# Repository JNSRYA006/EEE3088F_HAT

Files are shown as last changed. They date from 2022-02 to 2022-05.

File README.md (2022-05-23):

# Autonomous Plant Monitoring HAT for Discovery Board with STM32F051x8
This repository will be updated at each stage of the design process, and where necessary changes are made.

# Group Members:
* Ryan Jones (JNSRYA006)
* Alex Cargill (CRGALE002)
* Devlin Trafford (TRFDEV001)

# Project Details
### This project is part of a project for EEE3088F in 2022
This project will design a HAT *(Hardware Attached on Top)* for a STM Discovery Board which uses the STM32F051x8. The use case for this HAT is for semi-autonomous indoor plant growing. It will have a temperature sensor located as close to the plant as possible as well as a light sensor facing the main direction which the plant receives light from . These sensors will connect to a STM Discovery board, which will act as the brain of the system. This design was created for small scale agricultural setups. Appropriate user stories were applied to develop the Specifications. Given these use cases, the PCB is able to:

* Monitor the **temperature** around a plant
* Get precise readings of the **light level** a plant is receiving. 

See a 3D render of the PCB from KiCad below,

| PCB 3D Render |
| :----------------------------------------------------------: |

## Repository Structure
### Each sub-folder contains different aspects relating to different parts of the project
* ***PCB:*** The KiCad Project, Schematics, PCB & Layout and Project Libraries
* ***Firmware:*** Any software developed for the hardware or instructions on where to find relevant sofware in cases where it makes more sense to have this in its own dedicated repo
* ***Docs:***  Project documentation, Draft documents, ERC & DRC reports, project handins, schematic screenshot & documents and component datasheets
* ***Production:*** The final gerber files, BOM, Budget, or anything required by the fabrication houses
* ***Simulation:*** Any simulation files (SPICE) or design stage generated results (matlab or excel) 
* ***CAD:*** Any 3D models or mechanical designs for enclosures or support
# Hardware Requirements
 * [ ] STMDiscovery Board with an STM32F051x8 μC
 * [ ] 1 x MicroUSB to USB-A Cable
 * [ ] 1x MiniUSB to USB-A Cable
 * [ ] 8x Male to Female Jumpers

# Software Requirements

 - [ ] Computer 
	 - *Windows, Linux or MACOS*
 - [ ] STM32Cube IDE
	 - [Download available online](https://www.st.com/en/development-tools/stm32cubeide.html#get-software)
 - [ ] PuTTY
	 - [Download available online](https://www.chiark.greenend.org.uk/~sgtatham/putty/latest.html)

# How to short the UVLO circuit

- On the LHS of the board, remove resistor **R12 & R10** using pliers and twisting and pulling the resistors

- Q1 & IC1 (Circled in **Orange**) are the MOSFET & Op-Amp in the UVLO circuit that needs to be removed by soldering one end of a wire to the top pad (Pad 2) of R12 to the top pad (Pad 2) of R10 (Circled in **Green**)

  | UVLO_shorting |
  | :----------------------------------------------------------: |

# How to connect the power module to the rest of the board

- On the top, RHS of the board, solder a wire between **TP9** *OR* the **+3V** pin pad and the right hand pin of **J7**
  - This will connect the power from the power module to the rest of the circuit
- If connected correctly, when a battery is inserted or a USB is connected, a **Red** diode (**D9**) will turn on to indicate the sensing and microcontroller sub-circuits are receiving power.

# How to connect the PCB to the STMDiscovery Board

The following locations **on the PCB** need to be soldered to the male end of the jumper:

(*Refer to the KiCad PCB file [here](https://github.com/JNSRYA006/EEE3088F_HAT/blob/main/PCB/main/main.kicad_pcb) for the exact location of these*)

- PA1
- PA2
- PA9
- PA10
- PB6
- PB7

The female end of these jumpers are then connected to the corresponding pins on the STMDiscovery board.

# How to connect the PCB & STMDiscovery to your computer using UART

- Download and install CH340 drivers
  - [Download available online](https://learn.sparkfun.com/tutorials/how-to-install-ch340-drivers/all#drivers-if-you-need-them)
- Plug the device to your computer using a USB port. 
  - Check that the device is visible under ports in the Device Manager (for *Windows*), 
    - [Instructions on how to open Device Manager here](https://www.lifewire.com/how-to-open-device-manager-2626075)
- Create a serial connection with a baud rate of 18400bits/s in PuTTY

# How to send your first data to the board!

- After connecting the board using the above instructions,
- Type “Hello HAT” into the console and press ENTER.
- The device will dump all information collected since the last time the device was connected to a USB host device in the terminal window

# Contributing to this project

You're more than welcome to contribute to this project! Please take a look at our CONTRIBUTING.md file linked here

# License

[Creative Commons Attribution 4.0 International license](https://choosealicense.com/licenses/cc-by-4.0/)

[MIT License](https://choosealicense.com/licenses/mit/)

#

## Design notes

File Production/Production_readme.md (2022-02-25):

# Production
This folder will include instructions for the production of the PCB and will including budgeting notes.

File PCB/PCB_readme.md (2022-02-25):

# PCB notes
## From Justin's notes:
"In this repository a second repo has been added as a submodule and is available in the libraries folder [here](./PCB/Library/kicad6-libraries/).  This is an example of storing all the symbols and footprints you collect and make over time in a single location.  Go and look at the source of this submodule [here](https://gitlab.com/r4space/kicad6-libraries.git).  

The advantage of this approach is that as you develop more PCBs you will collect and create an increasing number of custom symbols and footprints that are not provided in the std KiCAD libraries.  By adding this submodule to all of your projects you will always have access to this extended library.  The cost of this, however, is clearly that your project repos will get increasingly large as your personal library grows.  In the context of collaborative work in a company, this would not be a problem and the company likely has exactly such a custom in-house set of libraries and the repos are not released to a client with the entire submodule but rather a specific release repo is made for this.

For the project, this is an effective way of starting your own libraries repo and collaborating.

At any point, you are able to enter the folder containing this submodule and updating it via a normal git pull."

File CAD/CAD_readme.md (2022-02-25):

# Project CAD Files
This folder will contain all files related to mechanical design for the project such as 3D printing or other container design files.

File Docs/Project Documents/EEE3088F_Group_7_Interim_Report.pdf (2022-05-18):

# EEE088F 2022 Interim Design Report Autonomous Plant Monitoring HAT for Discovery Board with STM32FC051

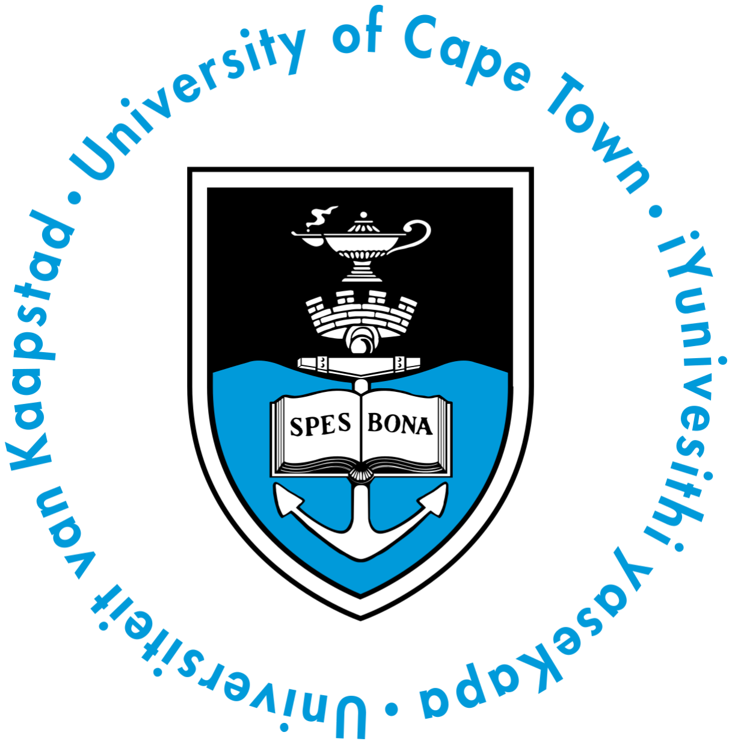
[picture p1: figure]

# JNSRYA006 TRFDEV001 CRGALE002

22/04/2022

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
cific

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
olle

r in

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
olle

r in

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
al [

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
# 1 Executive Summary [5]

The following report documents the design process and current design of a Discovery Board HAT (Hardware Attached on Top) for a STM32 Microcontroller. The use case for this HAT is for semi-autonomous indoor plant growing. All fianl PCB design files are available in a GitHub repository at this link. (https://github.com/JNSRYA006/EEE3088F_HAT)

This design was created for small scale agricultural setups. Appropriate user stories were applied to develop the Specifications. Given these use cases, the PCB is able to: Monitor the temperature around a plant, get precise readings of the light level a plant is receiving. These measurements can then be used to integrate with a control system that can adjust the temperature and light that a plant receives.

This device was thoroughly designed and the PCB has dimensions of: 96.01 mm x 70.01 mm, weighs ~0.11kg per board and costs $14.576 per board (excl. Shipping from JLCPCB). The device measures Temperature with an accuracy of (-10℃ to +85℃): ±1℃, at a 9-12 bit resolution. The device measures Light with an accuracy of < 3% Photocurrent Fluctuation versus Temperature Change (0℃ to 60 ℃) and the device operates at 5V via an input voltage from a USB or at 3.6V Input Voltage via 18650 Li-Ion Battery.

# 2 Introduction [15]

The use case for this project is autonomous and semi-autonomous indoor grow operations. This could be used in scenarios where someone would want to remotely monitor and control the environmental conditions of their growing operation or in scenarios where the operation is too large for the individual monitoring of environmental conditions and the system must self-monitor.

This sensing unit is designed to monitor two crucial factors in the growth of all crop-yielding plants: Heat and Ambient Light.
Most crop yielding plants grow in the temperature range of 15-30℃ (the large majority being around 21℃). Thus both sensors will need to operate effectively in this temperature range. It is also important that the ambient light sensor be sensitive to the spectrum of light required to grow plants.The wavelength of light that plants predominantly use for photosynthesis ranges from 600–800 nm. Thus the light sensor should be sensitive to this range of light frequencies.

These sensor readings would then be used to control the cooling/heating system and lighting system of the grow environment. This would allow for correction in the case of heat or light being sub-optimal.

Temperature Sensor Resolution: 9-12 bit resolution
Temperature Sensor Accuracy (-10℃ to +85℃): ±1℃
Light Sensor Accuracy: < 3% Photocurrent Fluctuation versus Temperature Change (0℃ to 60 ℃)
Operating voltage: 5V Input Voltage via USB OR 3.6V Input Voltage via 18650 Li-Ion Battery
Typical Power Consumption: 32324.16 mW = 32.32416 W
Cost:
- $14.576 per board
- Shipping from JLCPCB ≈ $26.53 for 5 Boards
- ~ $99.41 for 5 Boards (incl. shipping) Interfaces: USB, UART, I

2C, 1-wire protocol

## 2.1 Project Subsystems Block Diagram [10]

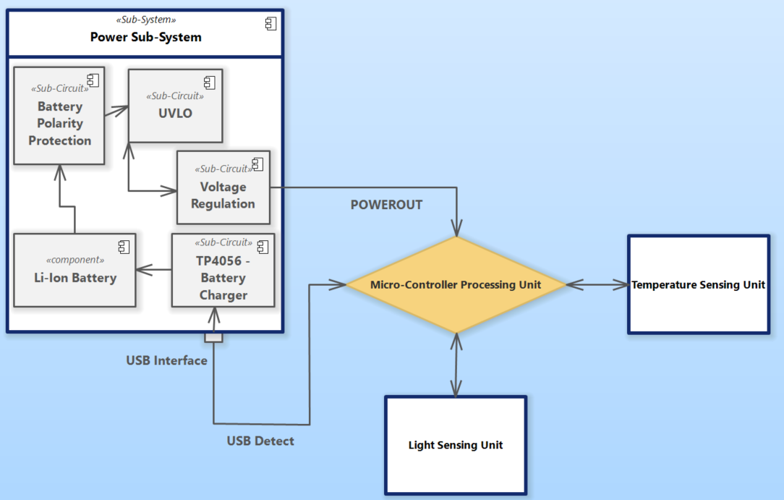
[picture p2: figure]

Figure 1: Project Sub-System Block Diagram

# 3 Specifications [15]

## 3.1 Power subsystem submodule [5]

### Sub-Module Top Level Specifications:

- Inputs:
- V | = 5V via USB Input at a maximum current of 4A CCIN ■ The typical current drawn will be ~2.5A
- V | = ~3.6V via an 18650 battery at a maximum current of 3A
BAT
| ■ The typical current drawn will be ~2.5A
- Outputs:
- V = 3.3V
OUT
- D+ & D- from USB to Microcontroller Sub-Module
- Visual User Communication Interfaces:
- The charging circuit has two LEDs (D5 & D6) located below the battery holder in the locations shown below in Figure 2.

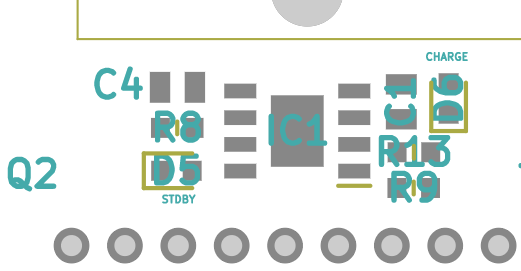
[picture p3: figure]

Figure 2: Location of CHARGE & STDBY LEDs on the PCB

Charge State | Red LED (CHARGE) | Green LED (STBY)
Charging | ON | OFF
Battery Fully Charged | OFF | ON
Vin too low | OFF | OFF
No battery connected | OFF | OFF
Figure 3: LED Charging State Table
- Furthermore, there is a Red LED located next to the USB input IC (MICROXNJ) that shows whether or not a USB has been detected using the following state table.

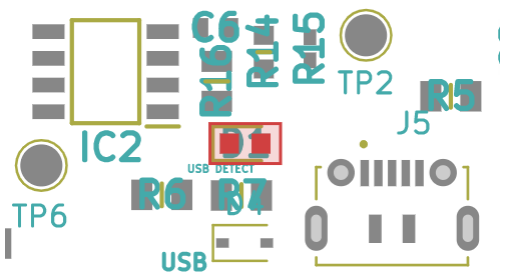
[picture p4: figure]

Figure 4: Location of USBDETECT LED on the PCB

USB Connection State | Red LED (USBDETECT)
NO USB Connected | OFF
USB Connected | ON
Figure 5: USB Connection State Table
- Interfaces with other modules:
- 3.3V will be delivered by the Power Module to the 3V3 Pin (Pin 1) on the 32 pin connector (J2). The other modules will access this power from the pin.
- Within the sub-module, the ICs will connect to each other in as short a routing as possible. With this, before each power pin of each IC, a decoupling capacitor has been added to remove any noise in the power provided to the ICs.

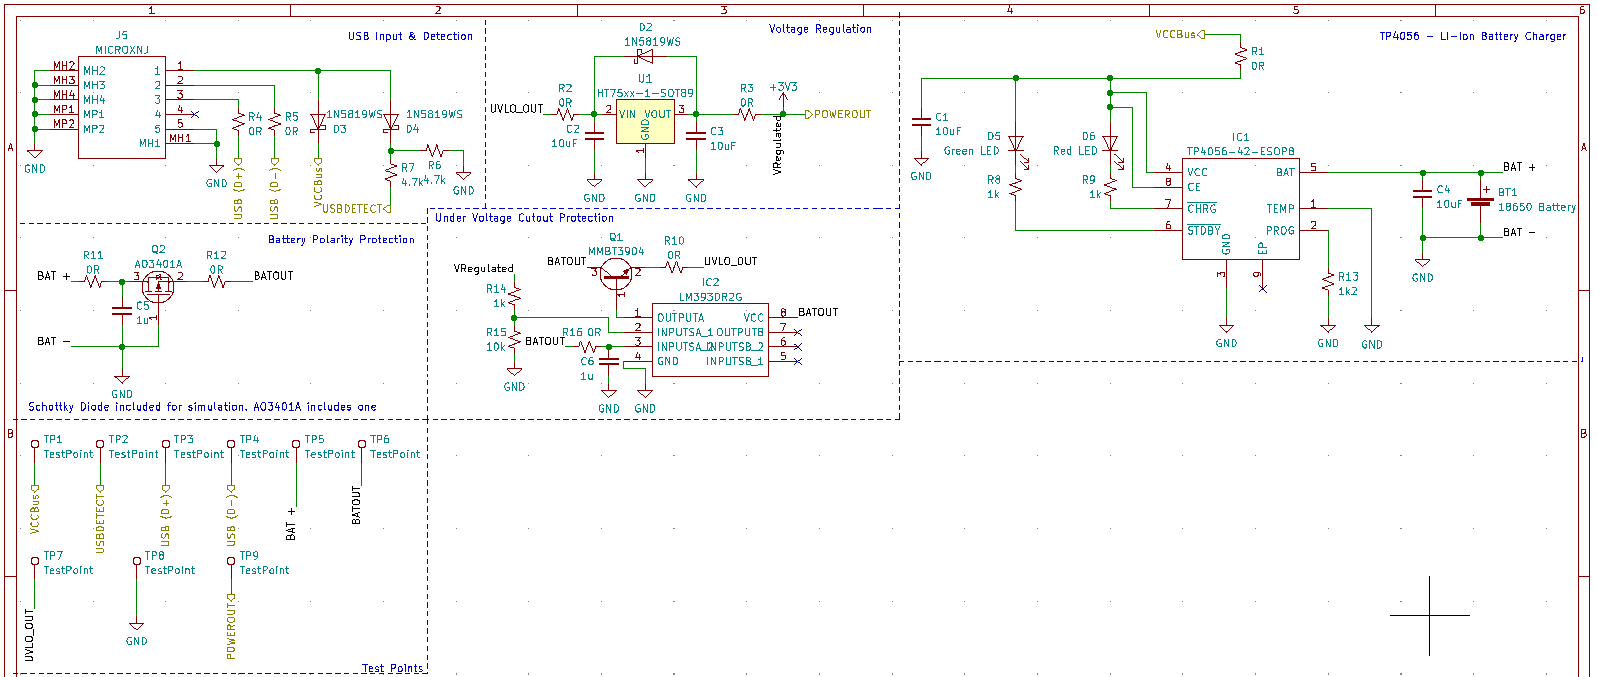
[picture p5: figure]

Figure 6: Power Subsystem Schematic v1.0

Full Size Image available on GitHub here (Better Quality) (https://github.com/JNSRYA006/EEE3088F_HAT/blob/main/Docs/Schematic%20Schreenshots/Power_Module_v1_0.png)

GitHub Link to KiCad Schematic available here (https://github.com/JNSRYA006/EEE3088F_HAT/tree/main/PCB/main)

Whilst the design has been meticulously thought through and improved throughout the design process, there are still uncertainties surrounding the functioning of the UVLO circuit. Other than this, the design is expected to function as intended. Should it not function as intended, there are test points located in between each sub-module of the power system. These test points will allow the parts of the circuit to be shorted. This will mean that if a sub-system is faulty, it can be ‘removed’ from the circuit. This process of introducing isolating within the module, as well as isolating the sub-system from the rest of the circuit using jumpers will allow any unexpected errors to be mitigated should they arise.

The issues with the UVLO are around the uncertainty of the functioning of the MOSFET and the comparator (LM393DRG). The suspected issue for the UVLO, is that the MOSFET will not operate in the correct mode when the comparator detects a low voltage coming into the circuit. Should this issue come to fruition, Test Point 6 can be connected to Test Point 7. This will cut the UVLO sub-system out of the Power system and hopefully mitigate any issues caused by the UVLO.

## 3.2 Microcontroller interfacing submodule [5]

### Original Submodule Specifications:

Overall:
- This submodule will take 3.3V and draw a maximum of 50mA.
- This submodule will operate between 0°C and 40°C.

EEPROM:
- This submodule will contain 2kB of EEPROM with 16 bit pages that will be accessed through the I

2C protocol.
- This submodule will use a microcontroller to communicate with its EEPROM at a rate of 400kB/s.

USB to UART:
- This submodule will allow for microcontroller to computer communication through a USB to UART chip that will talk to the microcontroller at a Baud rate of 2400bps.

Sensing Connections:
- This submodule will convert two incoming analog sensor signals to binary data using an ADC and store both in its EEPROM.
- This submodule will store 8 bit samples in its EEPROM.
- This submodule will store incoming binary data from a digital sensor in its EEPROM.
- This submodule will have debugging capabilities in the form of female connectors that can be probed using an oscilloscope.

Current EEPROM Specifications (AT24C256C):
- 400kHz (1.7V) and 1MHz (2.5V, 2.7V, 5.0V) Compatibility.
- 2-wire Serial Interface (or I
2C)
- 256-Kbit with 64-byte pages.

Therefore this EEPROM satisfies the specifications and exceeds the specifications in terms of storage space.

Current USB to UART Specifications (CH340G):
- Baud Rate ranges from 50bps to 2Mbps.
- Allows for USB to UART communication with the STM microcontroller.

Current Sensing Connections Specifications:
- Many of this module’s specifications will be done using code. Although the connections have been made such that it will be possible to store sensor data in the EEPROM and to sample the analog sensor using an ADC in the STM board.

Overall, this submodule meets the specifications for supply voltage and maximum supply current. Furthermore all components can operate within the specified temperature range. The specifications for each internal module have also been met.

The USB to UART module has some risk associated with the TXS0108EPWR, which might not be able to level shift the incoming USB 2.0 data at such high speeds. This might cause distortion of the USB signal and loss of information. There are test points which might be used to bypass the Level Shifter if required. Furthermore the entire USB to UART module can be disconnected from the STM board.

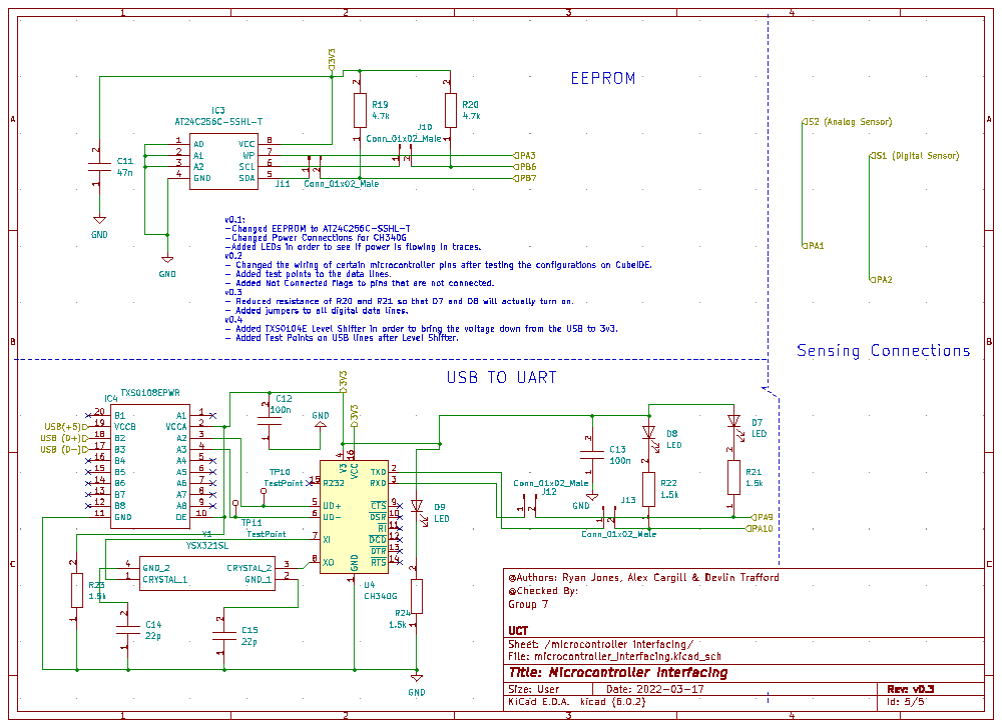
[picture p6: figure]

Figure 7: Microcontroller Subsystem Schematic v1.0

Full Size Image available on GitHub here (Better Quality) (https://github.com/JNSRYA006/EEE3088F_HAT/blob/main/Docs/Schematic%20Schreenshots/uC_Module_v1_0.png)

GitHub Link to KiCad Schematic available here (https://github.com/JNSRYA006/EEE3088F_HAT/tree/main/PCB/main)

## 3.3 Sensing submodules [5]

- Digital Sensor Specification DS18B20:
- VDD (Operating voltage): 3.3-5V
- IDD (Active current) :
- Standby current : <1 uA
- Max Voltage Range on any Pin wrt Ground: -0.5V to +6.0V
- Operating Temperature Range: -55°C to +125°C
- Output data protocol: 1-wire
- Accuracy : ± 1 °C
- Resolution: 9-12 bit
(writeable)
- Analog Sensor Specification ALS-PD15-21B-TR8:
- VCCin : 1.8V to 5.5V
- Standby current: <1 uA
- Operating temperature:-40C to 85C
- VCCmax: 0.5 ~ 6 V
- Output Voltage: 0 ~ VCC-0.6 V
- Output Photo Current: 0 ~ 5 mA
- This module should output an analogue voltage reading between 0V and 3.3V.
- Sensitive to the desired light spectrum for growing indoor plants (between 600 and 800 nm).
- Low photocurrent fluctuation versus temperature change (15 to 30 ℃).
- Operable at 3.3V

This a good design since both sensors will be operating in their recommended temperature and voltage range. The light sensing module is sensitive to the desired light spectrum and both sensors have a sufficient degree of accuracy. Additionally both sensors have a low standby current which means the module is also energy efficient in its idle mode.

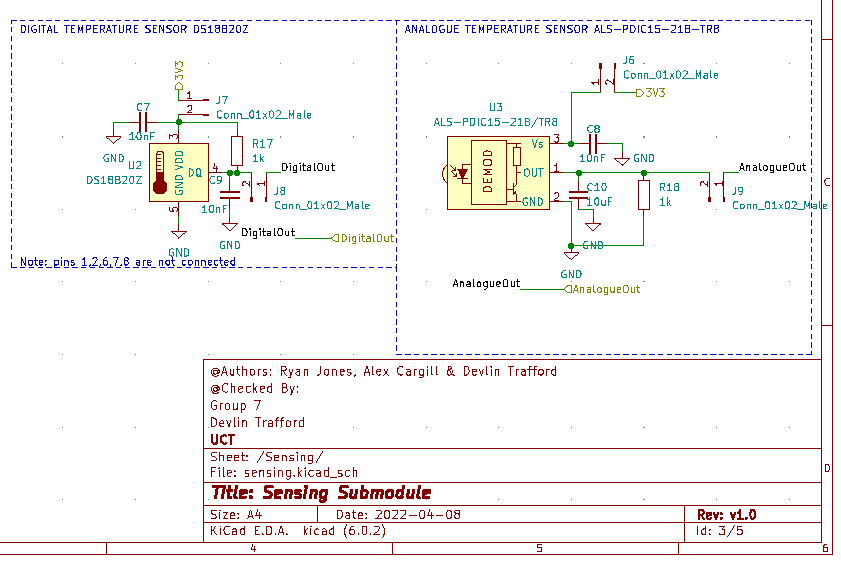
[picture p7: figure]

Figure 8: Sensing Subsystem Schematic v1.0

Full Size Image available on GitHub here (Better Quality) (https://github.com/JNSRYA006/EEE3088F_HAT/blob/main/Docs/Schematic%20Schreenshots/Sensing_Module_v1_0.png)

GitHub Link to KiCad Schematic available here (https://github.com/JNSRYA006/EEE3088F_HAT/tree/main/PCB/main)

# 4 Power Budget Analysis [20]

## 4.1 Power submodule [6]

For the TP4056, there are multiple conditions that determine the Charging Current. The
decision to set R | means that the datasheet shows values for the charging
PROG = 1. 2kΩ
current (I | ) and trickle charge current ( | ). According to the datasheet, (https://dlnmh9ip6v2uc.cloudfront.net/datasheets/Prototyping/TP4056.pdf) | exists
| BAT I
TRIKL

I
TRIKL
when V | , where | is the threshold voltage for trickle charging. This voltage is
BAT < V
| TRKL V TRKL
in the range 2. 8V − 3. 0V. That means that when the voltage across the battery is less than this value, the current value supplied to the battery is lower than that of when the threshold has not been reached.
For the Power Budget, this trickle current was ignored, as I | will always be higher, so for
| | BAT
the sake of over estimating, the power will be calculated using I | rather than | and
| | BAT

I

| | | TRKL I
BAT
at different stages of charging.

Also note, that both LEDs will not have a minimum current, as regardless of the current that flows through, light will be emitted - it just may not be visible to the human eye.

NOTE 1: All ICs’ values are for when Temperature = 25℃.
NOTE 2: If no Maximum Power value available, the Typical value was used in the Maximum Power Total. If no Minimum Power value as well, the Typical Power Value was used.
Component | Supply Voltage (nominal V) | Minimum Current (mA) | Typical Current (mA) | Maximum Current (mA) | Minimum Power (mW) | Typical Power (mW) | Maximum Power (mW)
MICROXNJ | 5 | - | 1800 | - | - | 9000 | -
HT7533-1 | 3.6 | 70 | 100 | - | 252 | 360 | -
AO3401A | 3.6 | 0.25 | 2500 | 4000 | 0.9 | 9000 | 14400
TP4056 -ESOP8 | 5 | 950 | 1000 | 1050 | 4750 | 5000 | 5250
1N5819WS | 5 | - | 1000 | 3000 | - | 5000 | 15000
| 3.3 | - | 1000 | 3000 | - | 3300 | 9900
LM393DR2G | 3.6 | 6 | 16 | - | 21.6 | 57.6 | -
Red LED | 5 | - | 20 | 25 | - | 100 | 125
Green LED | 5 | - | 20 | 25 | - | 100 | 125
Totals | | | | | 22524.5 | 31917.6 | 54217.6

Therefore, the total Power for:
- Minimum Power = 22524.5 mW = 22.5245 W
- Typical Power = 31917.6 mW = 31.9176 W

- Maximum Power = 54217.6 mW = 54.2176 W

## 4.2 Microcontroller interfacing submodule [6]

Component | Supply Voltage (nominal V) | Minimum Current (A) | Typical Current (A) | Maximum Current (A) | Minimum Power (W) | Typical Power (W) | Maximum Power (W)
AT24C256C-SSHL-T | 3.3 | 6u | 2m | 3m | 19.8u | 6.6m | 9.9m
CH340G | 3.3 | 0.08m | 4.8m | 12m | 0.264m | 15.84m | 39.6m
YSX321SL (Level of Drive) | N/A | N/A | N/A | N/A | 1u | 100u | 200u
TXS0108EP WR | V =3.3 a V = 5 b | - | - | 8u | - | - | 39.6u
Pull-Up Resistor for OE Pin | 3.3 | 0.314m | 0.33m | 0.347m | 1.04m | 1.089m | 1.15m
I2C Pull-Up Resistors | 3.3 | 0m | 0.7m | 1.4m | - | 2.31m | 4.62m
UART Line LEDs | 3.3 | 0m | 3m | 4.5m | 4.95m | 9.9m | 14.85m
Totals | | 0.4m | 10.83m | 21.255m | 6.275m | 35.84m | 70.36m
- For AT24C256C-SSHL-T, minimum supply current is given for Vcc=5V and for no read or write operations.
- For the CH340G, minimum current is given for the USB Suspended state only.
- YSX321SL is a crystal oscillator which doesn’t have a supply voltage or current specified, although power dissipation is specified.
- Only a maximum supply current specified for TXS0108EPWR, the chip has two supply voltages and therefore the maximum current is the sum of the current drawn by each supply.
- The Pull-Up Resistor has a tolerance of 5%. This gives the minimum and maximum current values.
- The UART and I

2C LEDs will only turn on during transmission so the maximum represents the case where all the lines are pulled low and all the LEDs are conducting while the minimum represents the case where no data is being actively transmitted.

## 4.3 Sensing submodules [6]

Component | Supply Voltage (nominal V) | Minimu m Current (mA) | Typical Current (mA) | Maximum Current (mA) | Minimum Power (mW) | Typical Power (mW) | Maximum Power (mW)
DS18B20 (Digital temperature sensor) | 3.3 | 0.005 | 1 | 1.5 | 0.0165 | 3.3 | 4.95
ALS-PD15-21B-TR8 (Analog sensor) | 3.3 | 0.001 | 0.2 1 (Note 1) | 5 | 0.0033 | 0.66 | 16.5
Totals | 3.3 | 0.006 | 1.2 | 6.5 | 0.0198 | 3.3 | 21.45

## 4.4 System Total [2]

Submodule | Supply Voltage (nominal V) | Minimum Current (mA) | Typical Current (mA) | Maximum Current (mA) | Minimum Power (mW) | Typical Power (mW) | Maximum Power (mW)
PSU | 5 | 70 | 2500 | 4000 | 22524.5 | 31917.6 | 54217.6
Sensor1 | 3.3 | 0.005 | 1 | 1.5 | 0.0165 | 3.3 | 4.95
Sensor2 | 3.3 | 0.001 | 0.2 | 5 | 0.0033 | 0.66 | 16.5
Memory | 3.3 | 0.006 | 2 | 3 | 0.0198 | 6.6 | 9.9
Microproce ssor | 3.3 | - | - | 120 | - | - | 396
Totals | | | | | 22920.54 | 32324.16 | 54644.95
- Microprocessor has only a maximum current that it can draw from the supply, depending on the function the board is fulfilling at a particular time the power usage can be much lower than this.

1 Typical current at ~3.3V and 1000 Lux

# 5 Design process [10]

Decided to use temp and light sensors because other sensors were unavailable and extended parts. Temperature and light sensors are easier to test due to being able to manipulate both of those environmental conditions. In the microcontroller subsystem, the CH340G was chosen for its very low price. The FTDI is far too expensive to be considered for this project.

### Revisions:

v0.1:
- Changed EEPROM to AT24C256C-SSHL-T because there is more programming support for this chip through better documentation. The chip is slightly more expensive, but is also higher specification.
- Added LEDs in order to see if power is flowing in traces. These are for debugging purposes. One can see when the UART or I

2C lines are pulled low by the open drain.
- The initial temperature sensor (TMP117AIDRVR) had leads which were too small to accommodate efficient testing.
- The next temperature sensor (DS18B20Z+T&R) was too expensive ($9.32) so the cheaper version (DS18B20Z) of the same chip was chosen

v0.2:
- Changed the wiring of certain microcontroller pins after testing the configurations on CubeIDE. It was discovered that the STM only supports UART and I

2C on very
specific pins.
- The initial light sensor chosen (DY-PD204-6B) was through-hole and since the group wished to only have SMT parts, this sensor was replaced by the ALS-PD15-21B-TR8 which also had markedly better accuracy and temperature stability.
- Removed the Schottky Diode from the Power Circuit in the Battery Polarity Protection sub-circuit as the AO3401A includes one as a barrier diode. This was an unnecessary inclusion in the circuit and the cost of the components could be reduced.

v0.3:
- Reduced resistance of R20 and R21 in the microcontroller subsytem so that D7 and D8 will actually turn on.
- Added jumpers to all digital data lines. These allow the isolation of the EEPROM and USB to UART modules as well as being testing points.

v0.4:
- Added TXS0104E Level Shifter in order to bring the voltage down from the USB to 3v3. The 5V data lines will likely break the CH340G unless level shifting is implemented.
- Added Test Points on USB lines after Level Shifter. These are to ensure that the signals are being level shifted correctly.
- Removed a logic system which would determine whether to use battery power or power from a USB. Removing this freed up budget for the rest of the circuit. Instead, the 5V USB line will always be run through the battery circuitry.

v1.0:
- All the jumpers initially chosen were through-hole so the design was revised to use SMT jumpers.
- Removed the Input Polarity Protection sub-circuit, as the USB detection circuit included Schottky Diodes which would prevent a negative input voltage, so a whole circuit was unnecessary and increased the circuit cost.
- Changed the Voltage Regulator IC from the AMS1117-3.3 to the HT7533-1. This was due to the AMS1117-3.3’s dropout voltage of 1.1V. This would make the AMS1117-3.3 not regulate voltage in scenarios where the board still required power and didn’t need to cutout the supply voltage.

# 6 Conclusion [10]

The sensors were chosen such that they operate effectively in the desired environmental conditions of 15-30 ℃ and light with a spectrum of 600-800 nm. Additionally both sensors have been chosen to be operable with a 3.3V input and low standby current. The design process of the sensing unit required fewer design iterations since fewer parts were required. The primary difficulty associated with the sensing unit was finding sensors which were inexpensive, SMT and had datasheets with the necessary information. The data from the light sensor is an analogue voltage signal and will be processed by the microcontroller’s ADC. The temperature sensor will give out digital using 1-wire serial data protocol. This microcontroller module has been designed to operate in conditions below 40℃ and with a maximum current draw of less than 50mA. The module facilitates the storage of sensor data in the EEPROM. Furthermore, it implements a USB to UART interface that can be used to interact with the HAT from a computer. The module features 3 LEDs which light up when the UART data lines are communicated properly. The main issues during design regard the USB to UART module, which required the interfacing with 5V USB data lines while using a power supply of 3.3V. The solution was determined to be a level shifting chip that will shift the incoming USB data to 3.3V and prevent the USB to UART chip (CH340G) from breaking. In order to use the USB to UART module from a computer, CH340 drivers must be installed on the USB host machine. Finally, the Power module made design decisions that reduced the need for extended parts, by making use of basic parts and attempting to most things from first principles rather than using expensive ICs. Throughout the design process, the priority was to make the circuits as simplistic, functional and cheap as possible. This was achieved through the removal of a seperate input polarity protection circuit , and rather using a singular diode.

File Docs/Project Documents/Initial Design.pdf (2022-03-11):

# EEE088F 2022 Initial Design Group 7

# JNSRYA006 TRFDEV001 CRGALE002

## Q1 Github [1]

GitHub Repository Link here (https://github.com/JNSRYA006/EEE3088F_HAT)

## Q2 Power Subsystem Failure Management [5]

Component failure/destruction, Trace Damage & Errors Post Manufacturing:

For component failure, trace damage & errors detected after manufacturing has been completed, the following points of the power circuit are able to be isolated, and excluded using jumpers which connect to the following pins on the STMDiscovery Board:

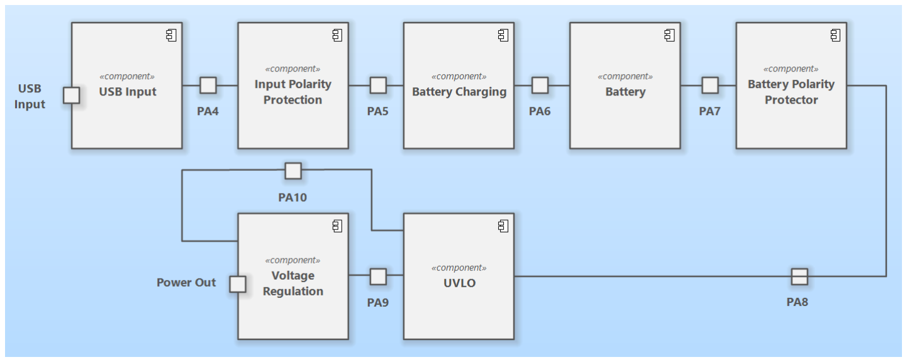
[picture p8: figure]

Figure 1: Diagram showing pin locations for jumpers in power module

Component Shortage:

Should there be a component shortage, alternatives for all components are available on JLCBPCB as basic parts and in similar price ranges except the AMS1117-3.3 (The voltage regulator), LM393DRG (Comparator in the UVLO), MICROXNJ (USB connector), 1N5819WS (Schottky Diode) & TP4056-42-ESOP8 (Battery Charger)

For these 5 ICs, the following alternatives are available:

Unavailable Component | Alternative Component | Alternative IC Part Number | Alternative IC Price | Price Increase per board
AMS1117-3.3 | AMS1117-3.3V | C173386 | $0.6858 | $0.5003
LM393 | LMS393DR | C67470 | $0.7862 | $0.6396
MICROXNJ | MICRO-01-G1P1-A1T2 | C2682504 | $0.6752 | $0.6256
1N5819WS | 1N5819W | C1884550 | $0.6146 | $0.6043
TP4056-42-ESOP8 | TP4056X-42-ESO P8 | C2763448 | $0.8511 | $0.5933

For all other components, such as resistors and capacitors, alternatives are available, as basic parts, for similar prices on JLCPCB.

## Q3 Sensing Subsystem Failure Management [5]

In the event of a component shortage, three alternative temperature sensors with similar specifications and cheaper or equivalent unit price have been found: these have the reference codes: LM75BDP, GX18B20U, LM70CIMMX-3/NOPB.

Additionally three alternative light sensors with similar specs and cheaper or equivalent unit price have been researched and found. Their references are: BH1603FVC-TR,

BH1680FVC-TR, ALS-PDIC15-21C/L230/TR8

Testing and debugging will be crucial for the sensing unit since it is the source of all of the project's input data. For the sensing sub-unit each sensor's data line will have connect/disconnect points in the form of male pins on the board which can be connected/disconnected via a female jumper. In the event that there is component damage/failure and the sensors are giving incorrect readings this will allow us to isolate their data outputs from the rest of the PCB and identify the cause of the issue without the consideration of all the other components and their potential for loading/distorting the sensor's readings . Each sensor will also have a connect/disconnect point from the power source. The sensor will also be positioned such that their data line traces are as far from any high current traces as possible. This is to minimise any noise that may be produced by the electromagnetic fields around these traces.

The sensors will also be positioned with space around them on the PCB in case of errors only detected post manufacture. This will allow for an easier modification of the circuit around the sensor should it be necessary.

Additionally sensors with relatively large pins were chosen to facilitate the placement of probes directly on the part for troubleshooting. If the part gets damaged and needs replacing this will also make for an easier job when desoldering it and resoldering a replacement.

## Q4 Microcontroller interfacing Failure Management [5]

(i) I have chosen an EEPROM and USB To UART chip that are surface mounted devices with long leads and therefore will be unsolderable if a device fails. The same applies to resistors and capacitors in the circuit.

(ii) Double traces with jumpers will be added in order to allow for backup traces that can be used in the case of trace damage. Also I added Leds in order to test whether traces are damaged or not.

(iii) There is a large family of CH340 chips that can be used as USB to UART chips. The
CH340G was chosen for its price and so there are a number of alternatives that are only slightly more expensive.

(iv) I have mentally prepared myself for the possibility. But apart from that I have inserted as many jumpers as our budget will allow in order to rewire connections. Furthermore, I will draw traces to unused pins in case they are needed once the board has been printed.

## Q5 Power Subsystem Schematic [10]

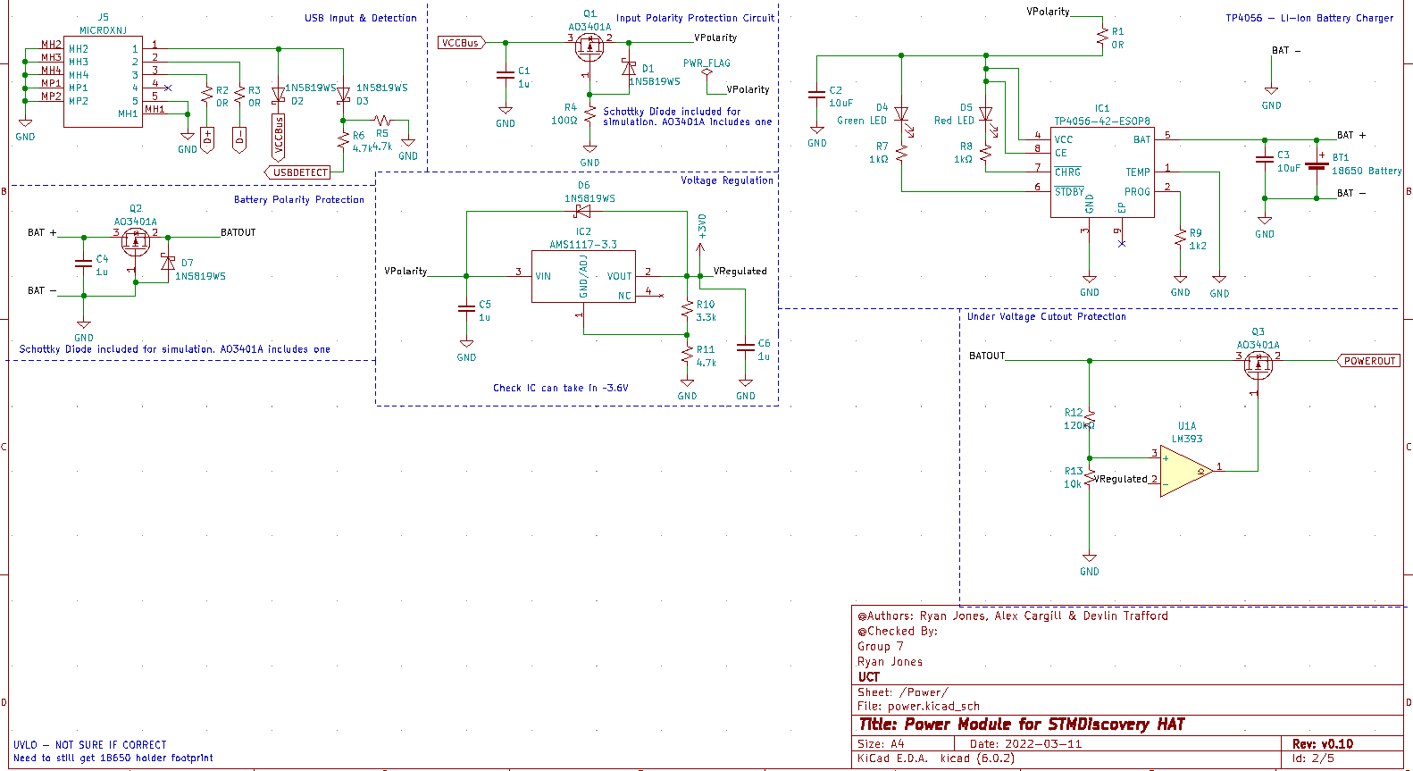
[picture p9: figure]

Click here for better quality image (https://github.com/JNSRYA006/EEE3088F_HAT/blob/main/Docs/Schematic%20Schreenshots/Power_Module_v0_1_0.png)

## Q6 Sensing Subsystem Schematics [10]

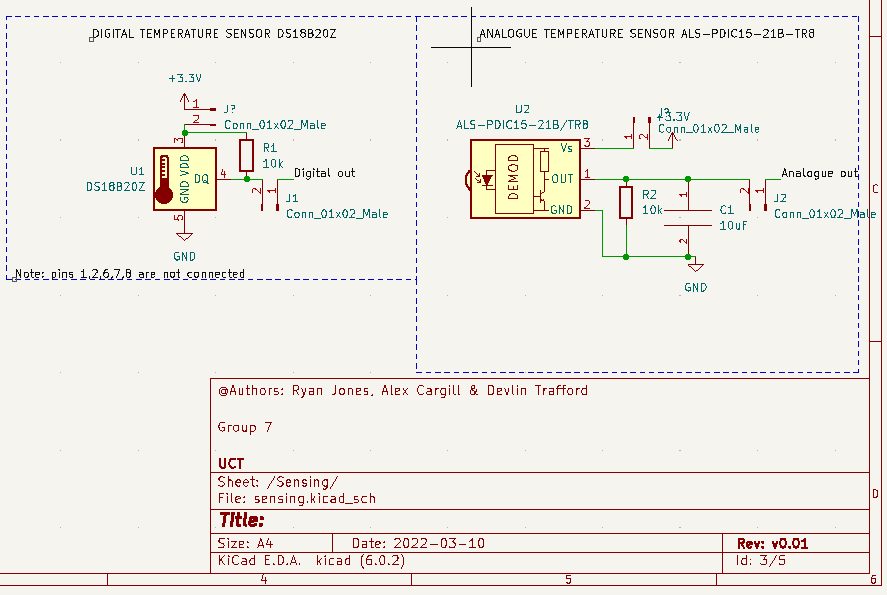
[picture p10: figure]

## Q7 Microcontroller interfacing Schematic [10]

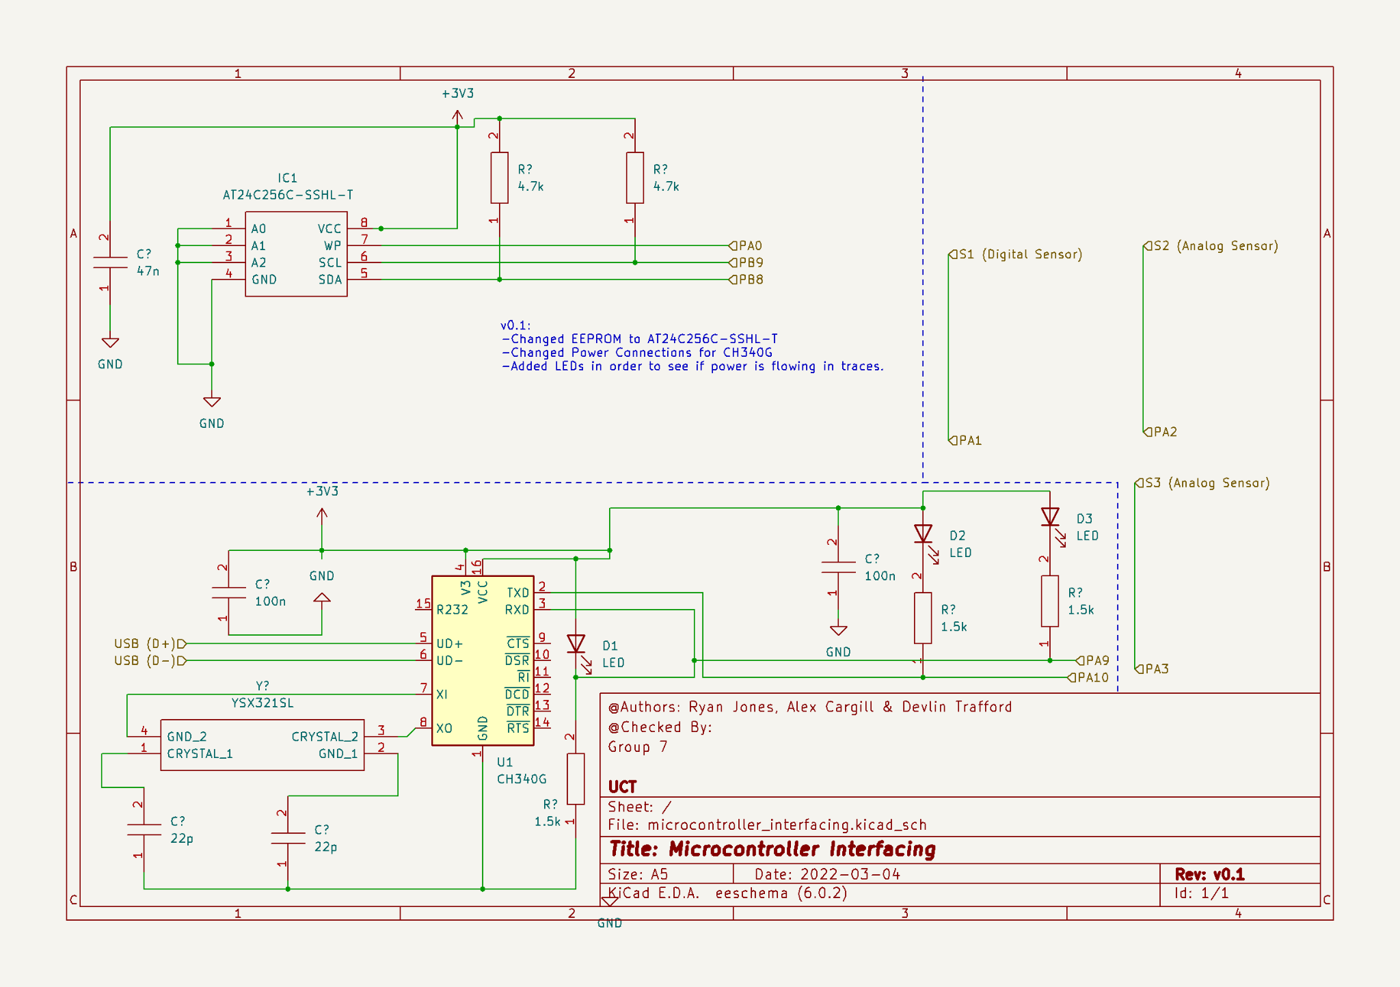
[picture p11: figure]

## Q8 Planned ERCs [5]

ERCs are designed to check if a circuit is electrically correct and connected correctly. This consists of the following checks if:

- All schematic connections are valid,
- There are any inputs or outputs that conflict,
- Any ports or pins are open and unconnected,
- And if any ports or pins overlap

KiCad gives a ERC.txt file after running an ERC, which is available on GitHub here. (https://github.com/JNSRYA006/EEE3088F_HAT/blob/main/Docs/ERC.txt)

The errors in the report are related to issues with hierarchical labels not being linked. This needs to be fixed, but does not impact the schematics of the submodule.

The same for the warnings in the report. These are related to labeling, that will be correct when a NetList is generated.

## Q9 Updated BOM [4]

Update BOM available on GitHub here (https://github.com/JNSRYA006/EEE3088F_HAT/blob/main/Docs/BOMs/Group_7_BOM_v0_1_0.csv)

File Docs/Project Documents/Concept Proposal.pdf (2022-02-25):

# EEE088F 2022 Concept Proposal Template

## JNSRYA006 TRFDEV001 CRGALE002

# Q1 Enviro sensing HAT Concept [5]

The HAT will be used as a water sensing module for agricultural purposes. It will have a moisture sensor located in the soil that the plants are growing in and a flow rate sensor connected to the irrigation system. These sensors will connect to a STM Discovery board, which will act as the brain of the system. This system is for indoor autonomous growing setups which has applications in disruptive agricultural industries like marijuana growing. The HAT is intended to be used in small scale, home-setups in order to automate the watering of the plant as well as small-scale, industrial applications in an emerging market.

# Q2 Requirements [10]

## An individual growing food in unsuitable climates/soil types

- R1.1: Requires regular watering for soil with high drainage rates
- R1.2: Requires very precise watering for high maintenance plants
- R1.3: Requires more efficient water consumption for areas experiencieng drought.

## Small Scale Industrial Agriculture

- R2.1: Too many plants to manually monitor with a small workforce requires water monitoring and automation.
- R2.2: More lucrative through larger crop yields and reduced workforce.
- R2.3: Lower water costs due to less wasted water.

## Quality Indoor Marijuana Growing

- R3.1: Automated watering systems provide better quality yield.
- R3.2: People who work long hours or travel would be able to maintain their grow remotely.
- R3.3: The ability to grow more plants due to not having to manually manage the water content of the soil in all the plants. This results in higher yield of the crop due to the automation of the watering.

# Q3 Project Subsystems Block Diagram [5]

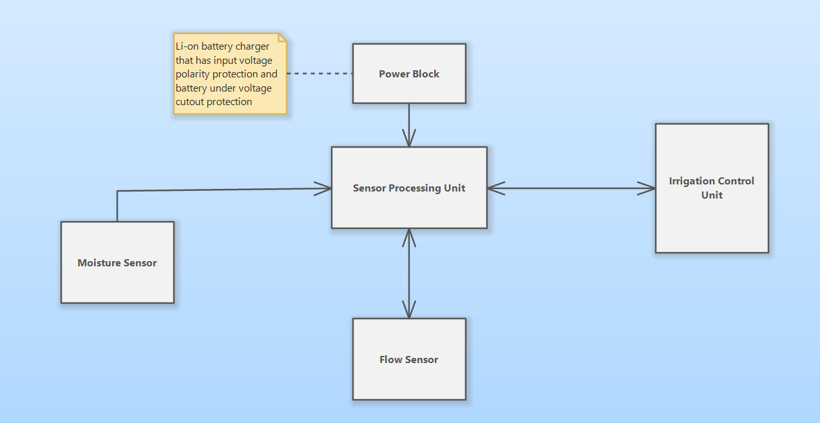
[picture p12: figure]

# Q4: Link to Team Git Repo [5]

- GitHub Repo: https://github.com/JNSRYA006/EEE3088F_HAT

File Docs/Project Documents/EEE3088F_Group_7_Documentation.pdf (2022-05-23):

# EEE088F 2022 Documentation & Software Autonomous Plant Monitoring HAT for Discovery Board with STM32FC051

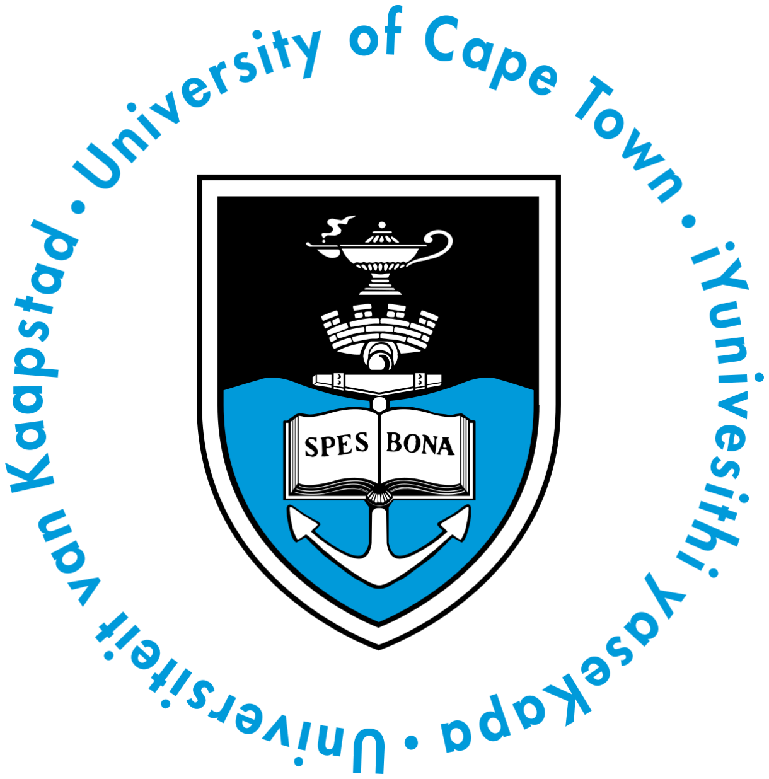
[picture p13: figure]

# JNSRYA006 TRFDEV001 CRGALE002

23/05/2022

# Section A: Software

# Q1 Code Structure [5]

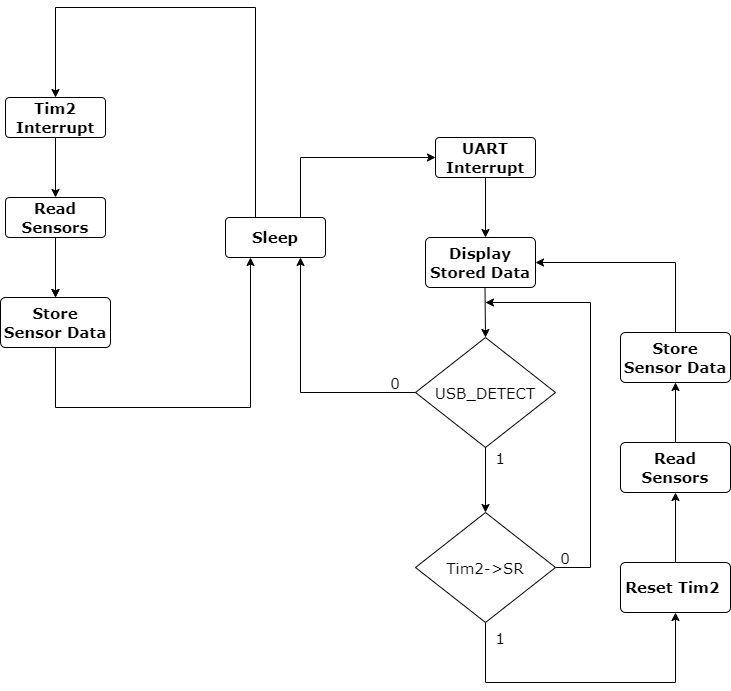
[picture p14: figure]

*When the USB is plugged in, the device is in a high power polling state.

## Figure 1: Code Block Diagram

# Q2 Code Reference [10]

### The following functions were used in the code to communicate and interface between the

HAT, STMDiscovery Board and the computer.

# Microcontroller Functions:

void HAL_TIM_PeriodElapsedCallback(TIM_handleTypeDef *htim) Function that runs when Tim2 Interrupt is triggered

void HAL_UART_RxCpltCallback(UART_HandleTypeDef *huart) Function triggered by user typing "Hello HAT"

void debugPrintln(UART_HandleTypeDef *uarthandle, char_out[ ]) Function that improves output to screen

int main(void)
Main function

# Sensor functions:

uint8_t DS18B20_Start (void)

### Initialises the digital sensor

void DS18B20_Write (uint8_t data)

### Takes a byte of data (as an argument) and writes it to the digital sensor

uint8_t read (void)

### Returns a byte from the digital sensors built in memory

The Full Code Reference document is available on GitHub here (https://github.com/JNSRYA006/EEE3088F_HAT/blob/main/Docs/Code%20Reference/Code_Reference_HAT_v1_0.pdf)

# Section B: Learning documentation:

# Q3 PCB Getting Started README: [10]

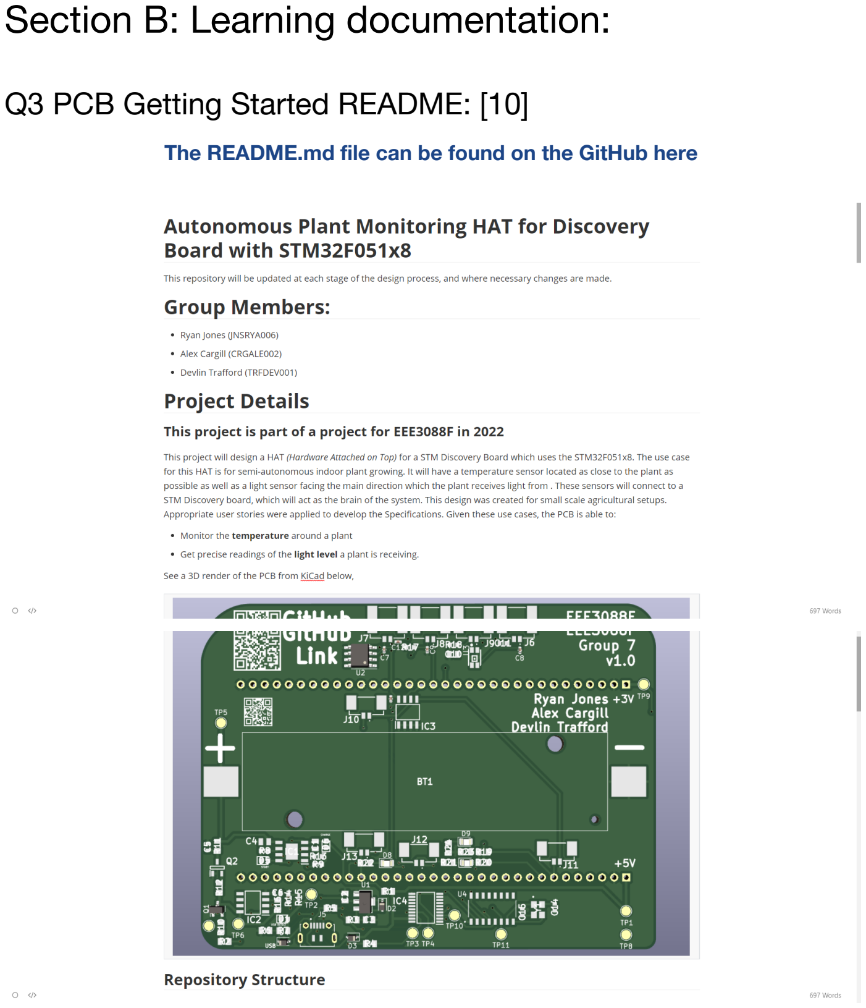
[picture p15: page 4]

The README.md file can be found on the GitHub here (https://github.com/JNSRYA006/EEE3088F_HAT/blob/main/README.md)

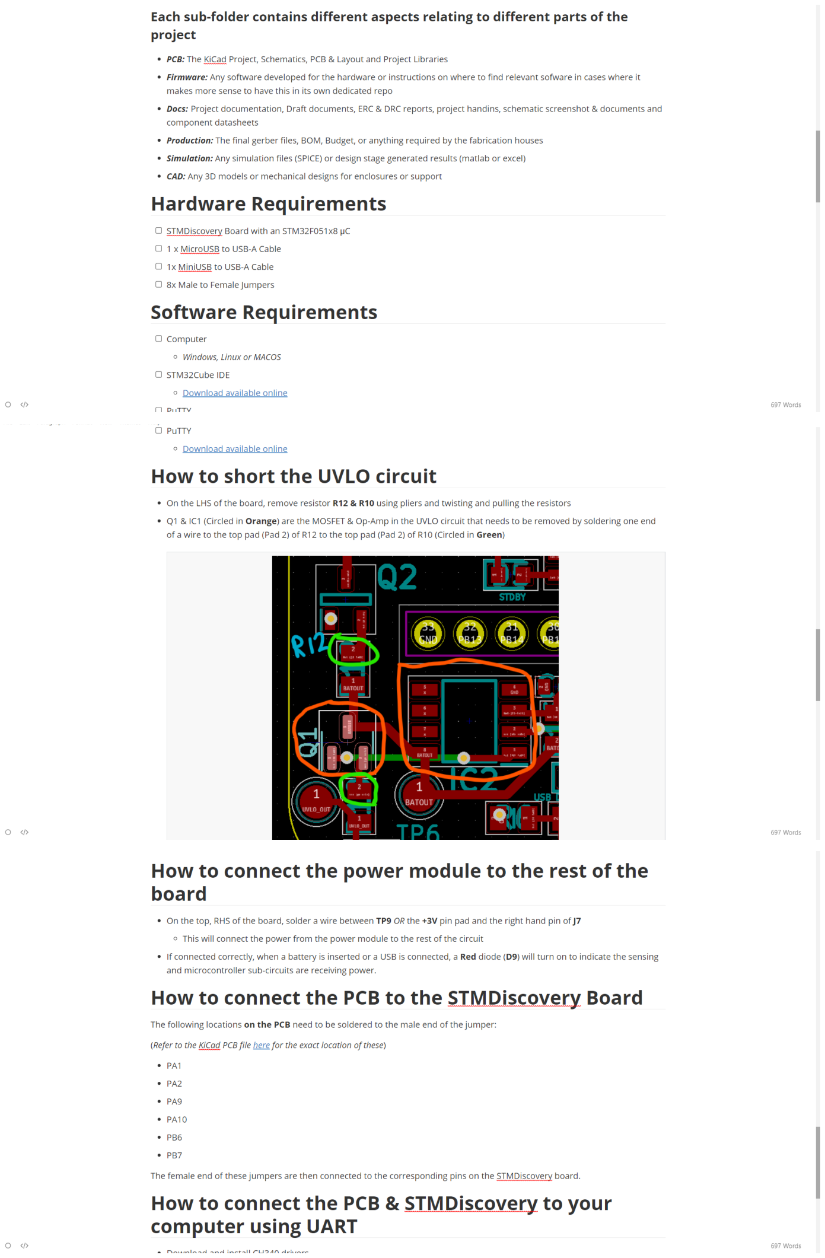
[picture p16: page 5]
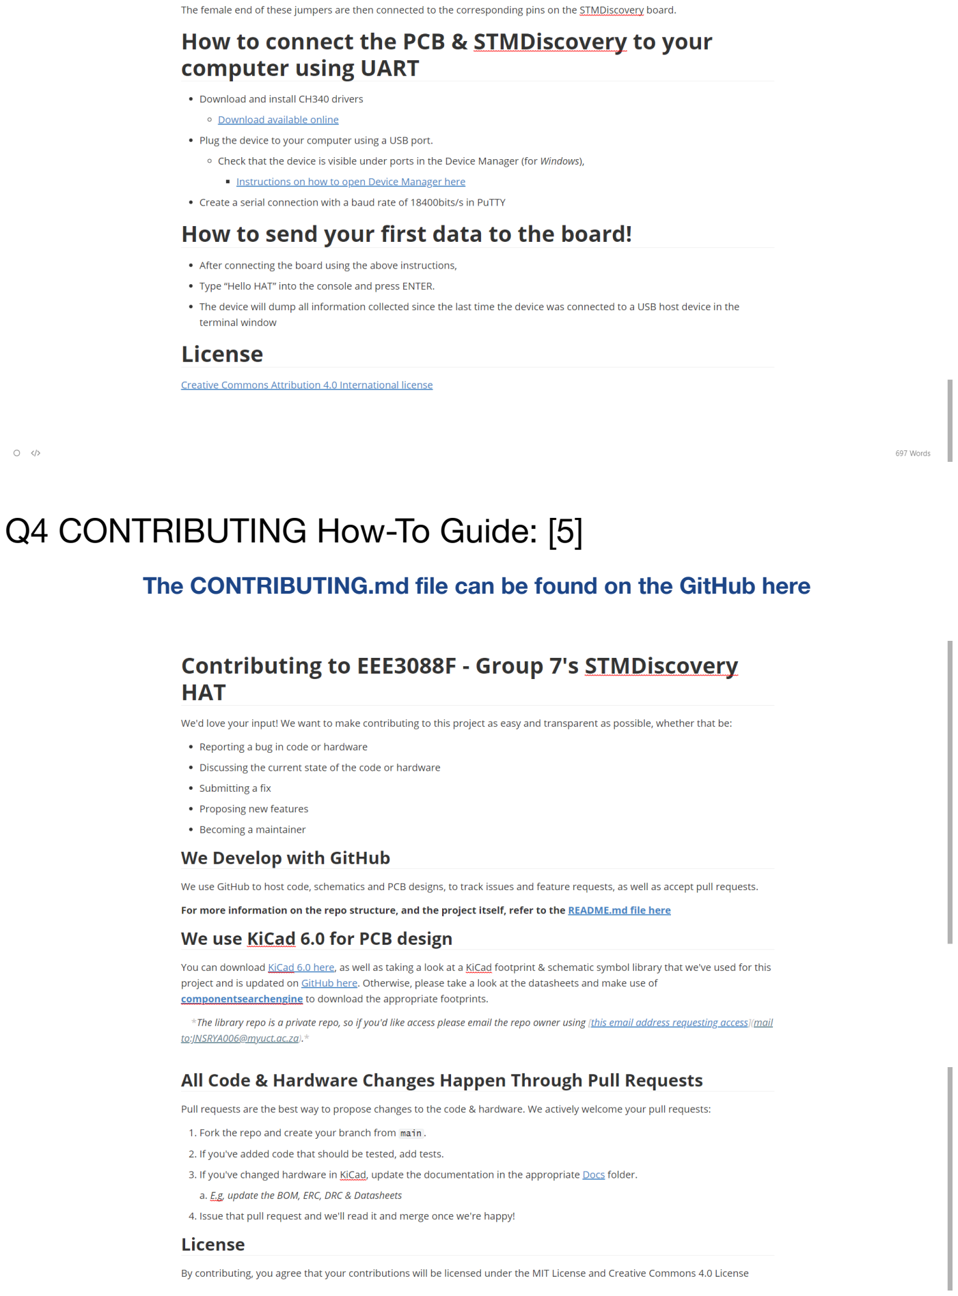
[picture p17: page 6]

# Q4 CONTRIBUTING How-To Guide: [5]

The CONTRIBUTING.md file can be found on the GitHub here (https://github.com/JNSRYA006/EEE3088F_HAT/blob/main/CONTRIBUTING.md)

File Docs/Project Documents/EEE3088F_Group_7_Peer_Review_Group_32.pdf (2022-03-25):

# Wk6 Peer Review of PCB

# Review of Group 32

# JNSRYA006 TRFDEV001 CRGALE002

## Peer Review of PCB Discovery HAT

For each of the following, rank each aspect on a scale of 0-5 where 0 is unacceptable and 5 is excellent. If you rank something as less than 5, indicate in the supplied comment section why you ranked this lower and what you would suggest changing.

### 1. Adherence to Mr Pead’s basic requirements. Have the requirements of the

project been met according to your understanding based not only on the initial project description but also based on all further lab presentations and design discussions. Consider ALL the implications of each of these in making your assessment. Reminder of basic requirements:
- (at least) 1x digital sensor (some communication port)✔
- (at least) 1x analog sensor (ADC input) ✔
- An 18650 connector (Do Not Populate - Link provided on Padlet) ✔
- A Li-Ion battery charger ✔
- Input voltage polarity protection ✔
- Battery polarity protection✔
- Battery Under-voltage cutout protection ✔
- (Soft requirement) Modularity between perceived elements to allow for bypassing to ensure you meet partial mark requirements in the event of module failure. ✔
- USB micro connector, detect and input and have an onboard FTDI - USB connector LCSC number provided on Padlet ✔
- Working in teams of 3 each team will have a budget of R1500 for all components, manufacture, assembly and shipping. Currently, this is approximately $100 (useful to think in USD as the part prices are listed in such) ✔
- Each team member must take the lead in 1 submodule:
- Power management
- Microcontroller interfacing
- Sensing
Unacceptable 1 | Ok attempt 2 | Reasonable 3 | Good 4 | Excellent 5
| | | | ✔

Comment:

We like the 3V regulation as it looks like it includes the UVLO, rather than needing an additional circuit. Furthermore, the choice of a P-MOSFET to protect battery polarity is clever as it is included in the supply switching circuit, again, rather than needing an additional circuit.
_________________________________________________________________________
2. ￼Adherence to Mr Pead’s debugger requirements. Have the requirements of the debugger been met according to your understanding based not only on the initial project description but also based on all further lab presentations and design discussions. Consider ALL the implications of each of these in making your assessment.

Reminder of high level debugger requirements:
1. Input 5V - This is to provide high level power to your board.
2. Analog Data - This is to both see what your sensor outputs and to push a signal into your board. If we are to push an analog voltage you need to ensure we don't destroy your sensor (So maybe a jumper to disconnect) ✔
3. Digital Data - Same story - we want to see it working / control it from off the board -where possible have the means to facilitate your systems not dying. ✔
4. Depending on what digital communication port you chose, I allowed for 4 pins.
5. Plug Detect is your USB detect line - which we can control and monitor to change your devices operation X
6. The data the device is sending out. (will need to disconnect the FTDI - Think Jumpers) ✔
7. GND ✔
Unacceptable 1 | Ok attempt 2 | Reasonable 3 | Good 4 | Excellent 5
| | | ✔
Comment:

There doesn’t seem to be an output that shows a USB has been detected. Some of the connections of the Microcontroller Interface module aren’t connected, so the traces on the PCB will not be connected because of this.

_________________________________________________________________________

3. Schematic Is the schematic neatly laid out, well labelled, are components labelled, is it clear what function each subsection serves.
Unacceptable 1 | Ok attempt 2 | Reasonable 3 | Good 4 | Excellent 5
| | ✔
Comment:

The light sensor needs an additional resistor below Vout because the datasheet says there is a constant Vce at ambient temperature. This means Vout will read 5V (as per the Vce on the datasheet) regardless of the amount of light incident on the sensor.

The Power Module includes a good idea of using the idea of a supply switch and, also using this switch to protect the circuit for polarity protection. The Power Module had a good choice of ICs as they seem to perform multiple functions and, according to the BOM, are also affordable choices.

_________________________________________________________________________

### 4. PCB Layout. Is the PCB neatly laid out, does it appear care has been taken

regarding trace location, routing, and thickness?
￼￼
Unacceptable 1 | Ok attempt 2 | Reasonable 3 | Good 4 | Excellent 5
| ✔
Comment:

There could be less vias, as some of them don’t seem necessary. Furthermore, some of the traces seem a bit long, and components could be placed a little closer together to reduce the length of traces and to make the layout a bit simpler. The trace width seems to all be the same size and not a bit larger to accommodate the 5V lines. _________________________________________________________________________

### 5. Silk screen. Is there a silkscreen, have key components been labelled that will

make a user and engineer’s life easier when they need to either service or use the board? Is there a version number and design name? Has space been well used?

Unacceptable 1 | Ok attempt 2 | Reasonable 3 | Good 4 | Excellent 5
| | ✔
Comment:

The Silkscreen doesn’t contain a version number and Design Name, The only values on the silkscreen are the component numbers and their outlines. Some of these are covered by the components, and considering the space around the components, these values could be more visible.
_________________________________________________________________________ ￼￼
6. Low voltage protection circuit (review on schematic). Based on the schematic, do you expect the circuit to function as expected?
Unacceptable 1 | Ok attempt 2 | Reasonable 3 | Good 4 | Excellent 5
| | | | ✔
Comment:

The chosen IC for the 3V regulation appears to solve the problem of Low Voltage Protection, rather than needing an additional circuit. It could be cool to include a LED to show a status, similar to the circuit shown in the datasheet. _________________________________________________________________________ ￼￼

### 7. Physical board design. Given the use case, is the size, shape, and layout of the

PCB well thought out?

Unacceptable 1 | Ok attempt 2 | Reasonable 3 | Good 4 | Excellent 5
| ✔
Comment:

The placement of the pins to the Discovery board, will mean that all the components on the PCB will be inaccessible whilst connected to the STMDiscovery. The choice to have the battery holder on the other side of the board is clever, as this component won’t fit in between the board and the STMDiscovery. The EdgeCuts layer on the board is missing/deleted, as when rendering the PCB, there is no defined size, so the whole schematic is filled. JLCPCB only accepts up to 100X100mm boards for cheap production, based on the project specifications. This means that there needs to be a defined EdgeCuts layer defined. The contents of the PCB also seem a bit spread out, and the placement of components could be closer together.

Furthermore, there seems to still be an additional pair of pins on the PCB which are unnecessary.
_________________________________________________________________________

### 8. Test points and recovery approaches. Are test points for each submodule

available, do you perceive them to be accessible and sufficient, is there any portion of the circuit that you think additional (or less) test points would be valuable? Are the mechanisms in place to handle failures of key components? (Eg jumpers and redundant routing). Consult the submitting team’s git repo where necessary to understand the design.

Unacceptable 1 | Ok attempt 2 | Reasonable 3 | Good 4 | Excellent 5
| ✔
Comment:

There are no test points for the data lines. There are not any jumpers which might be used to disconnect faulty modules. THis would be very useful in the power module. Jumpers would be useful on the sensing lines for the sensing submodule in order to test sensors before plugging them into the STM. Jumpers on the digital data lines would also be useful in order to test code in the event of one of the microcontroller interfacing submodules failing. They are quite easy to add and can be sourced cheaply. _________________________________________________________________________

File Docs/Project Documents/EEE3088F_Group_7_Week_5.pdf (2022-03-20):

# EEE088F 2022 Initial Design Template Group 7

# JNSRYA006 TRFDEV001 CRGALE002

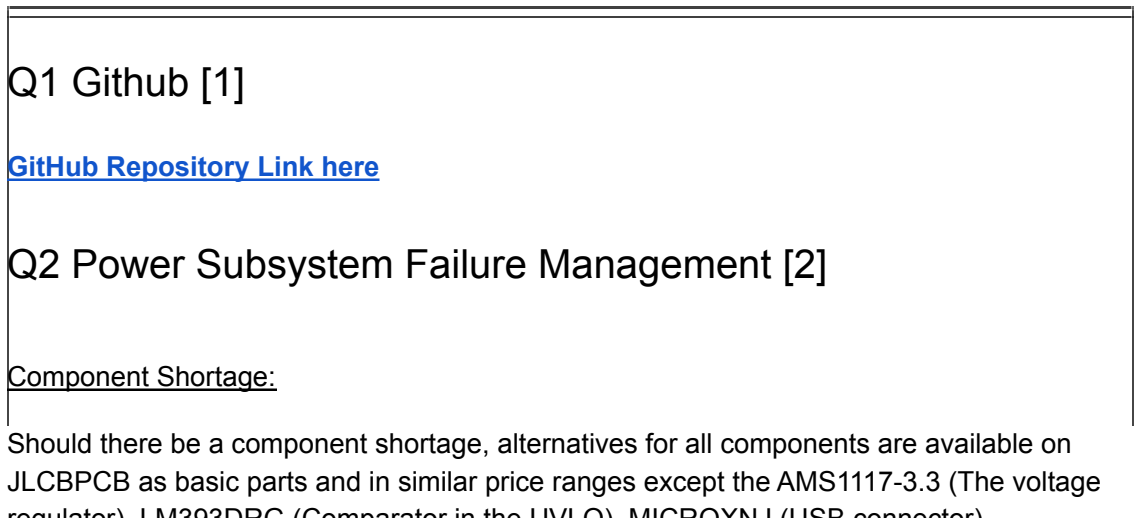
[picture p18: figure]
Q1 Github [1]; GitHub Repository Link here; Component Shortage:

## Q2 Power Subsystem Failure Management [2]

Should there be a component shortage, alternatives for all components are available on JLCBPCB as basic parts and in similar price ranges except the AMS1117-3.3 (The voltage regulator), LM393DRG (Comparator in the UVLO), MICROXNJ (USB connector), 1N5819WS (Schottky Diode) & TP4056-42-ESOP8 (Battery Charger)

For these 5 ICs, the following alternatives are available:

Unavailable Component | Alternative Component | Alternative IC Part Number | Alternative IC Price | Price Increase per board
AMS1117-3.3 | AMS1117-3.3V | C173386 | $0.6858 | $0.5003
LM393 | LMS393DR | C67470 | $0.7862 | $0.6396
MICROXNJ | MICRO-01-G1P1-A1T2 | C2682504 | $0.6752 | $0.6256
1N5819WS | 1N5819W | C1884550 | $0.6146 | $0.6043
TP4056-42-ESOP8 | TP4056X-42-ESO P8 | C2763448 | $0.8511 | $0.5933

For all other components, such as resistors and capacitors, alternatives are available, as basic parts, for similar prices on JLCPCB.

Component failure/destruction, Trace Damage & Errors Post Manufacturing:

For component failure, trace damage & errors detected after manufacturing has been completed, the… following points of the power circuit are able to be isolated, and excluded using jumpers which connect to the following pins on the STMDiscovery Board:

Figure 1: Diagram showing pin locations for jumpers in power module

…following Test Points have been included in the schematic design and correspond to the following points in the power module:

- TP1 - VCCBus (5V Supply from USB)
- TP2 - USBDETECT
- TP3 - USB (D+)
- TP4 - USB (D-)
- TP5 - Output of Input Polarity Circuit
- TP6 - Output of Battery Polarity Protection Circuit
- TP7 - Output of the UVLO
- TP8 - GND

## Q3 Sensing Subsystem Failure Management [2]

In the event of a component shortage, three alternative temperature sensors with similar specifications and cheaper or equivalent unit price have been found: these have the reference codes: LM75BDP, GX18B20U, LM70CIMMX-3/NOPB.

Additionally three alternative light sensors with similar specs and cheaper or equivalent unit price have been researched and found. Their references are: BH1603FVC-TR,

BH1680FVC-TR, ALS-PDIC15-21C/L230/TR8

Testing and debugging will be crucial for the sensing unit since it is the source of all of the project's input data. For the sensing sub-unit each sensor's data line will have connect/disconnect points in the form of male pins on the board which can be connected/disconnected via a female jumper. In the event that there is component damage/failure and the sensors are giving incorrect readings this will allow us to isolate their data outputs from the rest of the PCB and identify the cause of the issue without the consideration of all the other components and their potential for loading/distorting the sensor's readings . Each sensor will also have a connect/disconnect point from the power source. The sensor will also be positioned such that their data line traces are as far from any high current traces as possible. This is to minimise any noise that may be produced by the electromagnetic fields around these traces.

The sensors will also be positioned with space around them on the PCB in case of errors only detected post manufacture. This will allow for an easier modification of the circuit around the sensor should it be necessary.

Additionally sensors with relatively large pins were chosen to facilitate the placement of probes directly on the part for troubleshooting. If the part gets damaged and needs replacing this will also make for an easier job when desoldering it and resoldering a replacement.

Updates:

To mitigate the risks associated with trace damage, the sensing sub-module has been placed far from the other modules with generous spacing between traces. The sensors have also been placed in close proximity to the data pins which connect to the stm board, this was done so that in the event of trace damage, these sensors could be manually jumpered to their respective pins without needing long untidy jumpers.

## Q4 Microcontroller interfacing Failure Management [2]

(i) I have chosen an EEPROM and USB To UART chip that are surface mounted devices with long leads and therefore will be unsolderable if a device fails. The same applies to resistors and capacitors in the circuit.

(ii) Double traces with jumpers will be added in order to allow for backup traces that can be used in the case of trace damage. Also I added Leds in order to test whether traces are damaged or not.

(iii) There is a large family of CH340 chips that can be used as USB to UART chips. The CH340G was chosen for its price and so there are a number of alternatives that are only slightly more expensive.

(iv) I have mentally prepared myself for the possibility. But apart from that I have inserted as many jumpers as our budget will allow in order to rewire connections. Furthermore, I will draw traces to unused pins in case they are needed once the board has been printed.

Updates:

- In the event of a component shortage, the M24C64-RMN6TP can be used as a replacement chip for the AT24C256C-SSHL-T. It has lower storage, but still meets the overall project specifications and uses I2C to communicate. It is also slightly cheaper so it was a very close second choice for EEPROM initially. Using this chip would bring the budget down by 0.6$. The CH340G can be replaced by the CH340T. It is more expensive by 0.22$ so it will increase costs slightly, but it has the same features that are required for the USB to UART submodule.
- I have added silkscreens indicating what each test point is for. This will help during debugging.

## Q5 Power Subsystem Schematic [2]

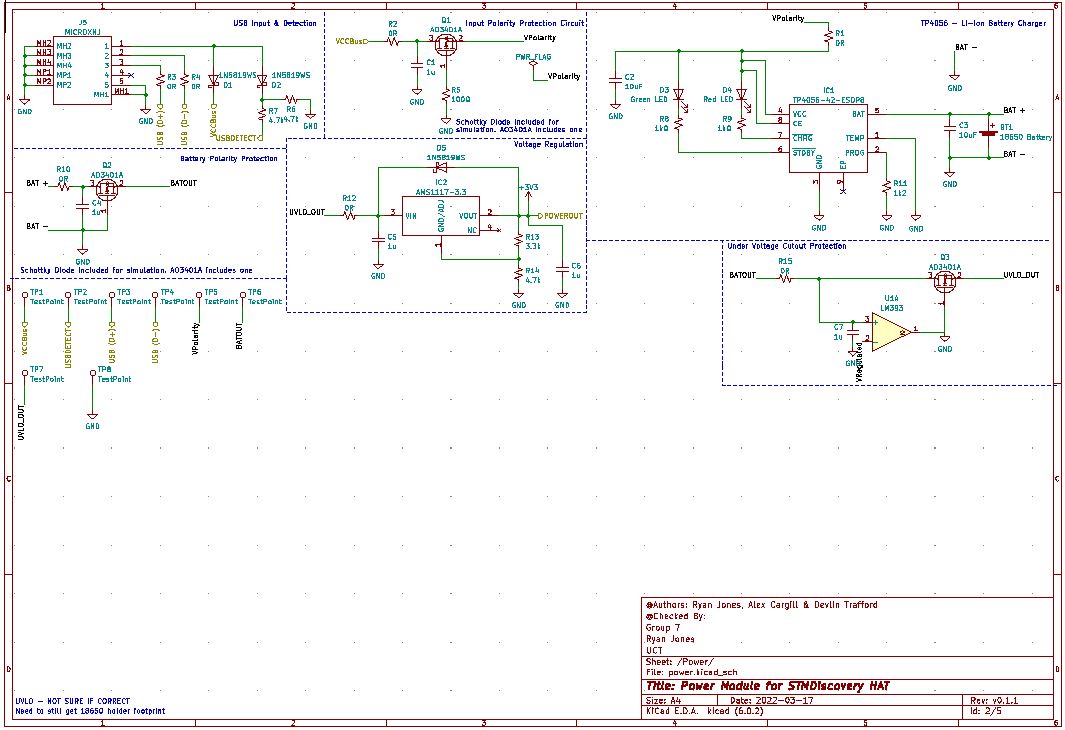
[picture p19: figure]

Figure 1: Diagram showing Power Module Schematic Please click here for a better quality image (https://github.com/JNSRYA006/EEE3088F_HAT/blob/main/Docs/Schematic%20Schreenshots/Power_Module_v0_1_1.png)

Updates:
- Added Test Points
- Allow testing across two points in the module and against GND
- Removed voltage divider at Pin 1 of U1A (Comparator - LMS393DRG)
- Not required, as the voltage at pin 1 (which is compared to reference voltage) is the voltage that needs to be compared
- Removed Schottky Diode (1N5918WS from polarity protection circuits)
- The A03401A includes one - the Schottkys were only included for simulation

## Q6 Sensing Subsystem Schematics [2]

No changes were made

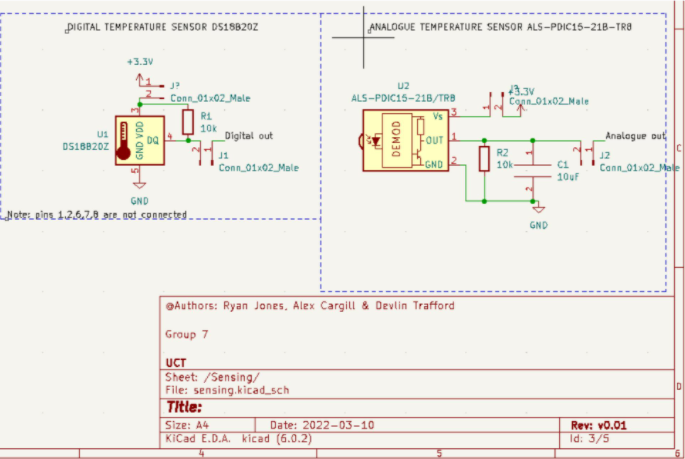
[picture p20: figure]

Figure 2: Diagram showing Sensing Module Schematic

## Q7 Microcontroller interfacing Schematic [2]

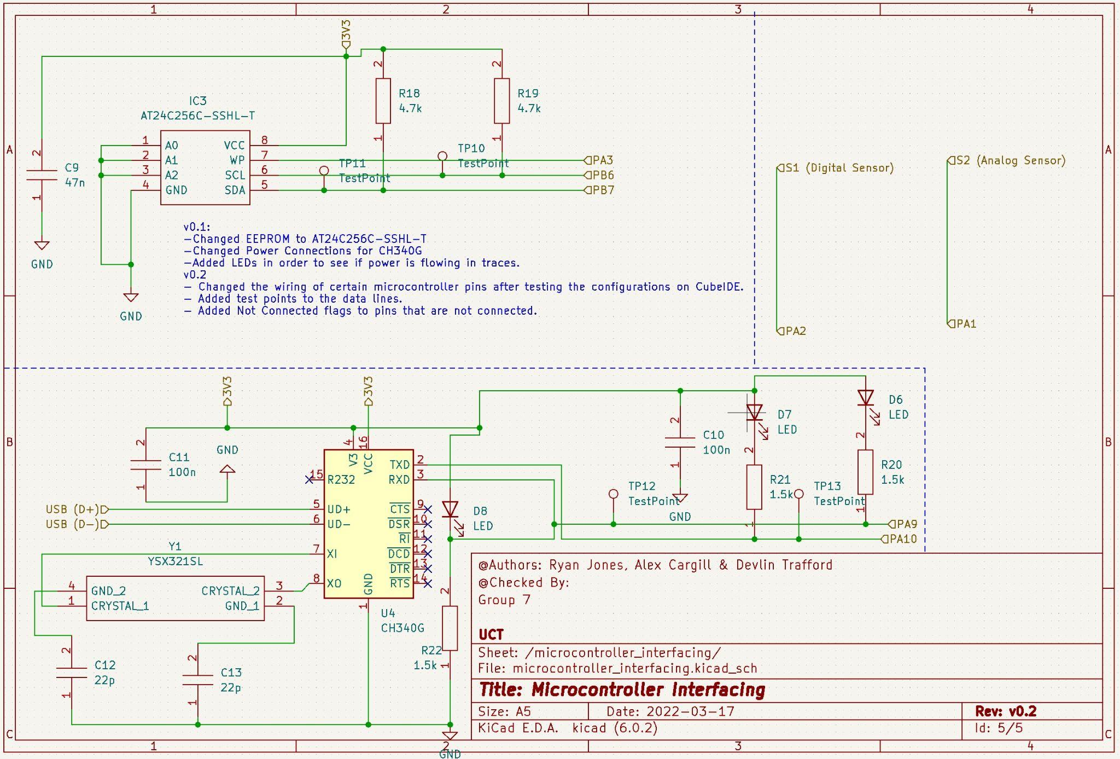
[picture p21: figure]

Figure 3: Diagram showing Microcontroller Interfacing Module Schematic

Updates:

- Added Test Points
- Added test points to the RXD and TXD data lines of the CH340G as well as to the SCL and SDA lines of IC3.
- Changed the connections between the microcontroller and the UART to USB and EEPROM submodules.

- I checked which pins were initialized in CubeIDE for the different communication protocols and found that they did not match those that I found online.
- Added Not Connected flags to unused pins.
- It was giving errors during the ERC.

## Q8 Updated ERCs [2]

ERCs are designed to check if a circuit is electrically correct and connected correctly. This consists of the following checks if:

- All schematic connections are valid,
- There are any inputs or outputs that conflict,
- Any ports or pins are open and unconnected,
- And if any ports or pins overlap

KiCad gives a ERC.txt file after running an ERC, which is available on GitHub here. (https://github.com/JNSRYA006/EEE3088F_HAT/blob/main/Docs/ERC.txt)

The output of the ERCs is also shown below as an image.

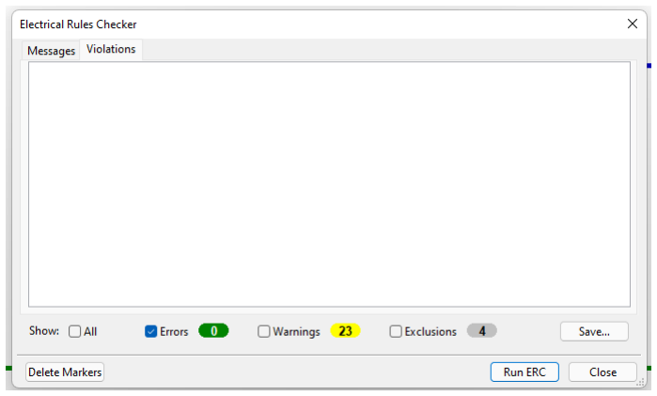
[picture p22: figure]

Figure 4: Screenshot after running ERCs in KiCad

The exclusions in the report are related to issues with symbol’s downloaded from the internet and the way that their pins have been set up. These exclusions produced a “Input Power pin not driven by any Output Power pins” error. These can be ignored, as changing the input type of a schematic symbol will fix these checks. Furthermore, 2 more of the exclusions were due to connectors, which in the PCB operation, will have a connection between them, so this error was excluded.

## Q9 DRCs [2]

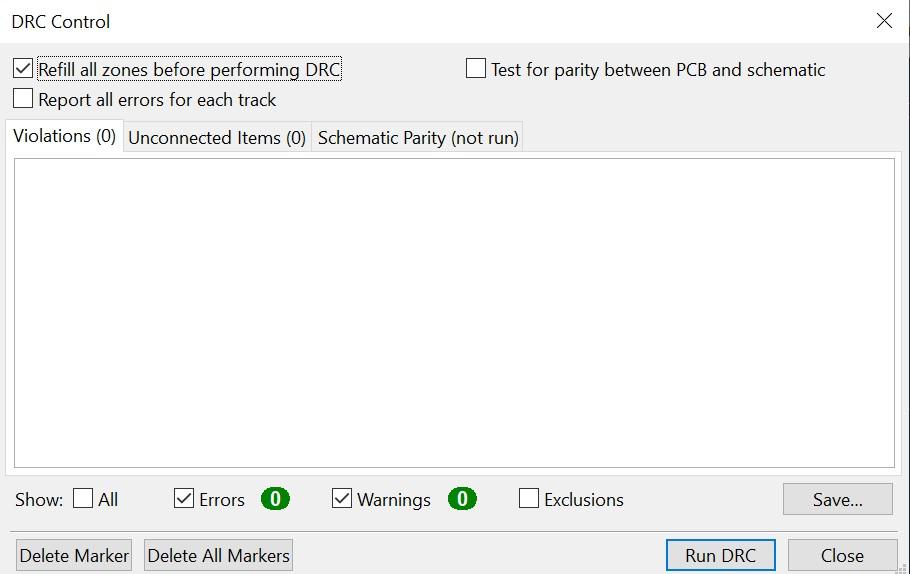
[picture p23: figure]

Figure 5: Screenshot after running DRCs in KiCad

No warnings or errors given. KiCad gives a DRC.txt file after running an DRC, which is available on GitHub here (https://github.com/JNSRYA006/EEE3088F_HAT/blob/main/Docs/DRC.txt)

## Q10 Updated BOM [5]

Link to BOM on GitHub Here (https://github.com/JNSRYA006/EEE3088F_HAT/blob/main/Docs/BOMs/Group_7_BOM_v0_1_1.csv)

Budget Total: $8.8033

## Q11 PCB [15]

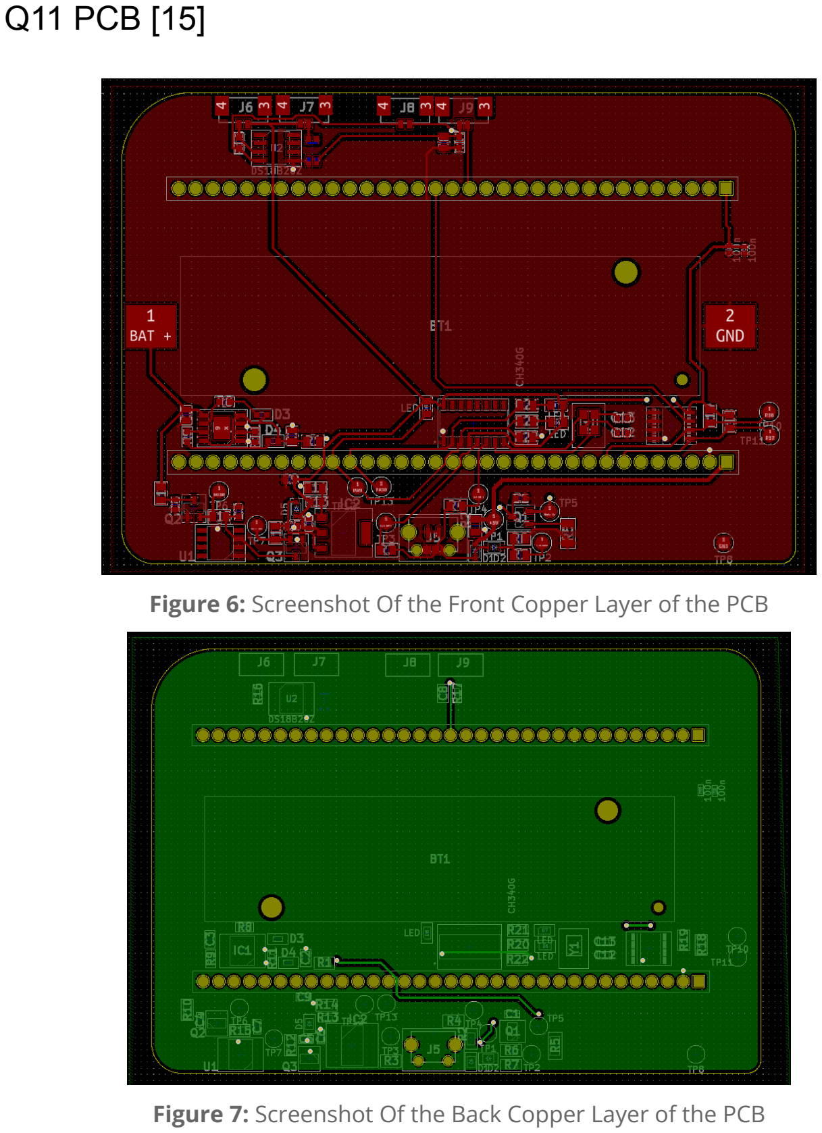
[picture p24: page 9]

Figure 6: Screenshot Of the Front Copper Layer of the PCB

Figure 7: Screenshot Of the Back Copper Layer of the PCB


Figure 8: Screenshot Of the Front Silkscreen & Fabrication Layers of the PCB

Figure 9: Screenshot Of the Back Silkscreen & Fabrication Layers of the PCB


Figure 10: Screenshot Of the Front of the PCB in 3D Viewer

Figure 11: Screenshot Of the Back of the PCB in 3D Viewer

Gerber Files in GitHub Here (https://github.com/JNSRYA006/EEE3088F_HAT/tree/main/Production/Gerbers)

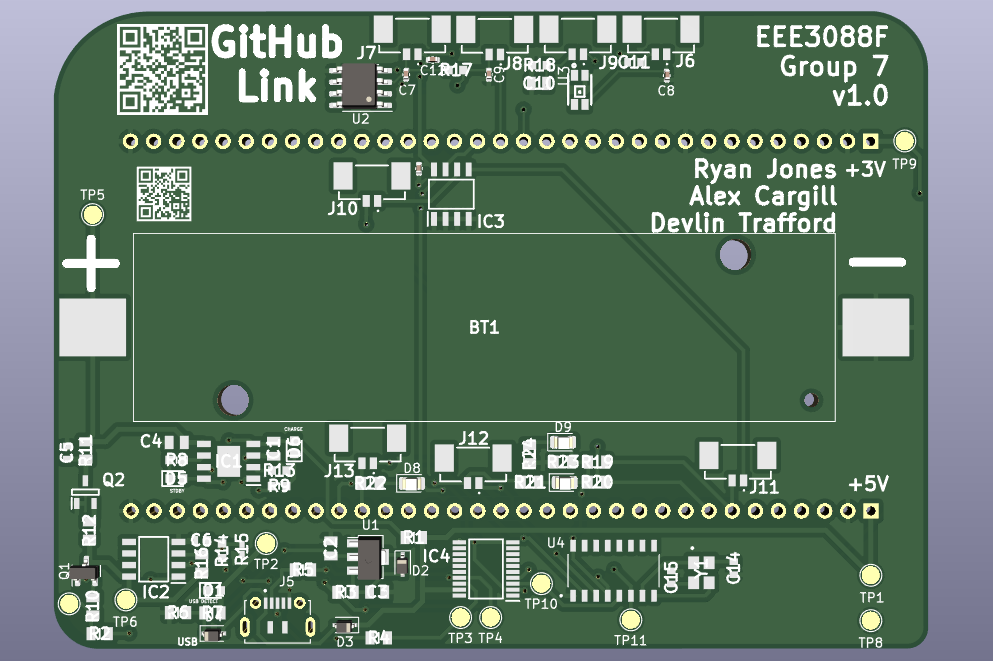
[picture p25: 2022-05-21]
Docs/Schematic Schreenshots/3D_Render.png

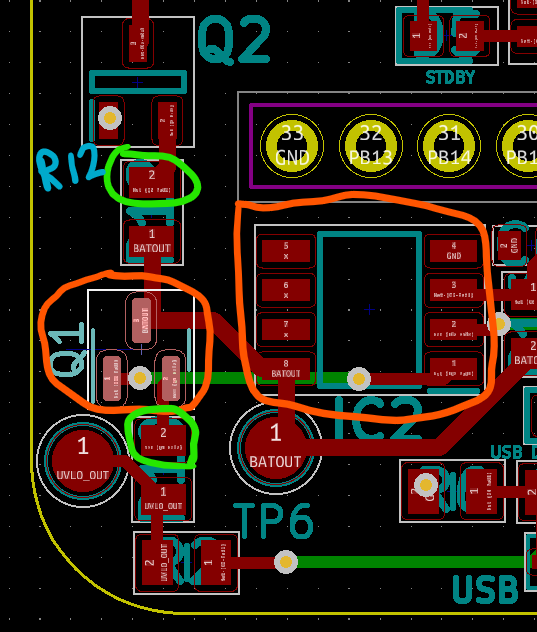
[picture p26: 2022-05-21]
Docs/Schematic Schreenshots/UVLO_shorting.png

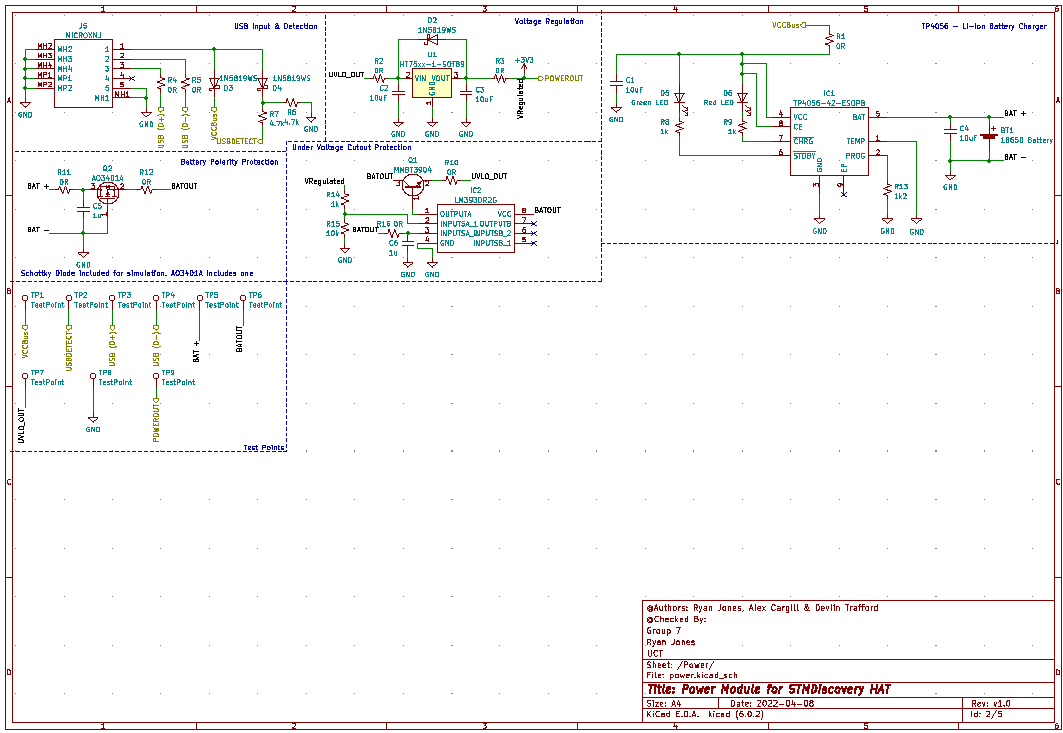
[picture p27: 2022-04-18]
Docs/Schematic Schreenshots/Power_Module_v1_0.png

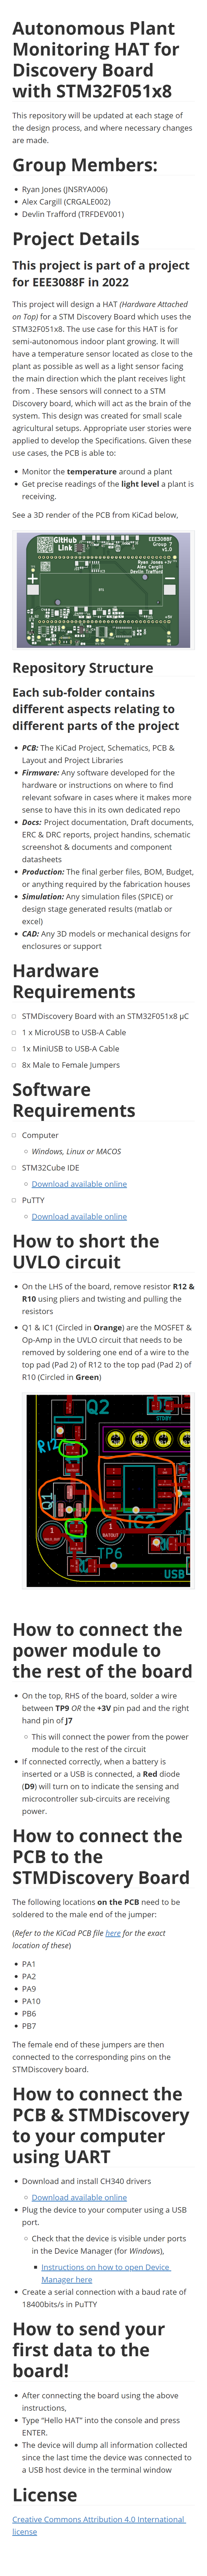
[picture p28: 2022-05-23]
Docs/Project Documents/README.png

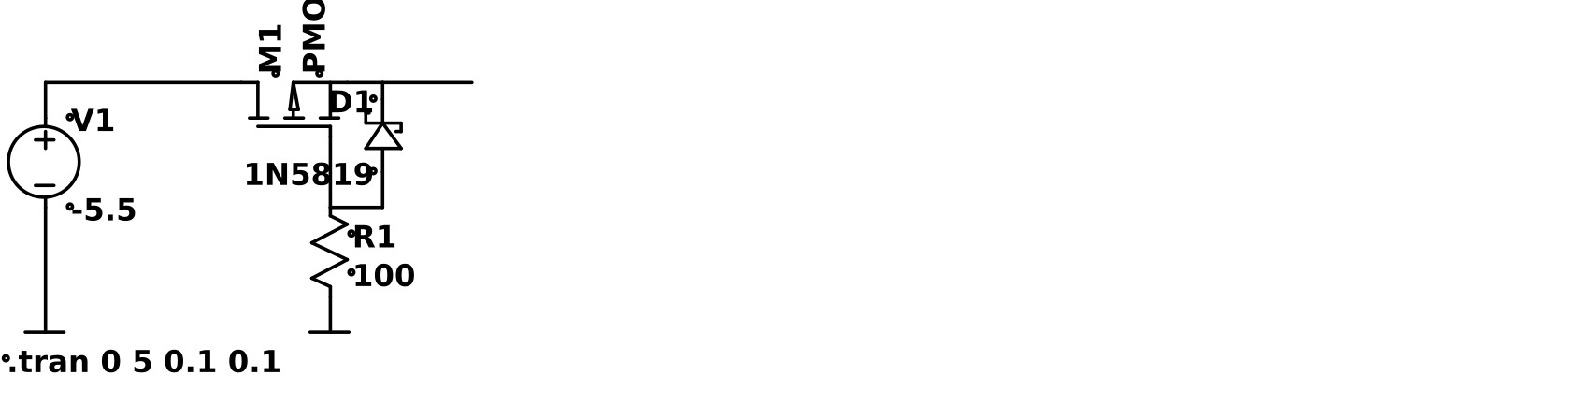
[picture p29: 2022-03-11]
Simulation/Power Module/Input-Voltage-Polarity-Protection-5_5V_Input.jpg

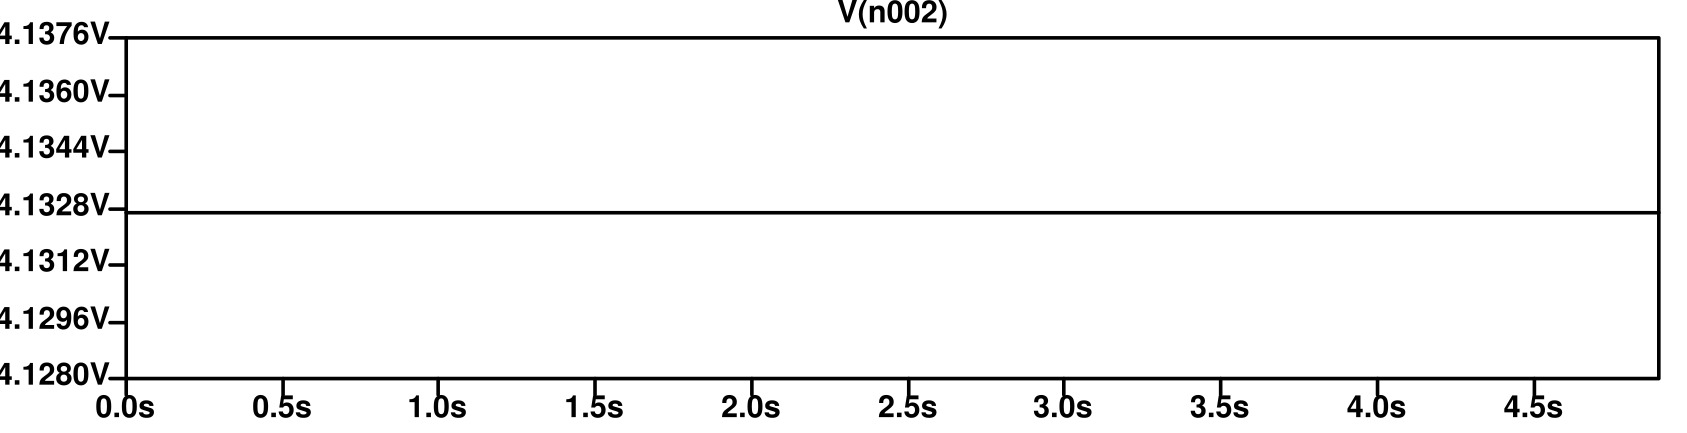
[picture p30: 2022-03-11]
Simulation/Power Module/Input-Voltage-Polarity-Protection-4_5V_Input.jpg

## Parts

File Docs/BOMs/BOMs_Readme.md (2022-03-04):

# All BOMs for draft and final schematics are available here

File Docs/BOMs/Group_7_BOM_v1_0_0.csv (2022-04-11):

Item | Qty | Reference(s) | Value | LibPart | Footprint | Datasheet | Alt_LCSC | Arrow Part Number | Arrow Price/Stock | Description | Field5 | Height | JLC Part Number | LCSC | Manufacturer_Name | Manufacturer_Part_Number | Mouser Part Number | Mouser Price/Stock | Populate | Price
1 | 1 | BT1 | 18650 Battery | Device:Battery_Cell | bat_holder:KEYSTONE-1042 | ~ |  |  |  |  |  |  |  |  |  |  |  |  | DNP
2 | 5 | C1, C2, C3, C4, C10 | 10uF | Device:C_Small | 10uF_0804:CAPC2012X145N | ~ |  |  |  |  |  |  | C19702 | C19702 |  |  |  |  |  | 0.068
3 | 2 | C5, C6 | 1u | Device:C_Small | 1uF_0804:CAPC1608X90N | ~ |  |  |  |  |  |  | C52923 | C52923 |  |  |  |  |  | 0.0037
4 | 3 | C7, C8, C9 | 10nF | Device:C_Small | Capacitor_SMD:C_0402_1005Metric | ~ |  |  |  |  |  |  | C15195 | C15195 |  |  |  |  |  | 0.001
5 | 1 | C11 | 47n | CL05B104KO5NNNC:CL05B104KO5NNNC | 47nF_0804:CAPC1608X90N | https://datasheet.datasheetarchive.com/originals/distributors/Datasheets-DGA10/2408147.pdf |  | CL05B104KO5NNNC | https://www.arrow.com/en/products/cl05b104ko5nnnc/samsung-electro-mechanics?region=europe | Samsung Electro-Mechanics CL05B104KO5NNNC 100nF Multilayer Ceramic Capacitor MLCC 16V dc +/-10% Tolerance SMD |  | 0.55 | C1622 | C1622 | Samsung Electro-Mechanics | CL05B104KO5NNNC | 187-CL05B104KO5NNNC | https://www.mouser.co.uk/ProductDetail/Samsung-Electro-Mechanics/CL05B104KO5NNNC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 |  | 0.004
6 | 2 | C12, C13 | 100n | CL05B104KO5NNNC:CL05B104KO5NNNC | Capacitor_SMD:C_0402_1005Metric | https://datasheet.datasheetarchive.com/originals/distributors/Datasheets-DGA10/2408147.pdf |  | CL05B104KO5NNNC | https://www.arrow.com/en/products/cl05b104ko5nnnc/samsung-electro-mechanics?region=europe | Samsung Electro-Mechanics CL05B104KO5NNNC 100nF Multilayer Ceramic Capacitor MLCC 16V dc +/-10% Tolerance SMD |  | 0.55 | C1525 | C1525 | Samsung Electro-Mechanics | CL05B104KO5NNNC | 187-CL05B104KO5NNNC | https://www.mouser.co.uk/ProductDetail/Samsung-Electro-Mechanics/CL05B104KO5NNNC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 |  | 0.0011
7 | 2 | C14, C15 | 22p | CL05B104KO5NNNC:CL05B104KO5NNNC | 22pF_0804:CAPC1608X90N | https://datasheet.datasheetarchive.com/originals/distributors/Datasheets-DGA10/2408147.pdf |  | CL05B104KO5NNNC | https://www.arrow.com/en/products/cl05b104ko5nnnc/samsung-electro-mechanics?region=europe | Samsung Electro-Mechanics CL05B104KO5NNNC 100nF Multilayer Ceramic Capacitor MLCC 16V dc +/-10% Tolerance SMD |  | 0.55 | C1653 | C1653 | Samsung Electro-Mechanics | CL05B104KO5NNNC | 187-CL05B104KO5NNNC | https://www.mouser.co.uk/ProductDetail/Samsung-Electro-Mechanics/CL05B104KO5NNNC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 |  | 0.0123
8 | 2 | D1, D6 | Red LED | Device:LED | Red_LED:LEDC1608X70N | ~ |  |  |  |  |  |  | C84256 | C84256 |  |  |  |  |  | 0.0139
9 | 3 | D2, D3, D4 | 1N5819WS | Diode:1N5819 | Diode_SMD:D_SOD-323 | https://datasheet.lcsc.com/lcsc/1810202112_Guangdong-Hottech-1N5819WS_C191023.pdf |  |  |  |  |  |  | C191023 | C191023 |  |  |  |  |  | 0.0103
10 | 1 | D5 | Green LED | Device:LED | Green_LED:LEDC1608X50N | ~ |  |  |  |  |  |  | C72043 | C72043 |  |  |  |  |  | 0.0312
11 | 3 | D7, D8, D9 | LED | Device:LED | LED_SMD:LED_0805_2012Metric | ~ |  |  |  |  |  |  | C2286 | C2286 |  |  |  |  |  | 0.0032
12 | 1 | IC1 | TP4056-42-ESOP8 | TP4056:TP4056-42-ESOP8 | TP4506:SOIC127P600X175-9N | https://datasheet.lcsc.com/szlcsc/1906261508_Nanjing-Extension-Microelectronics-TP4056-42-ESOP8_C16581.pdf |  |  |  | PMIC - Battery Management ESOP-8 RoHS |  | 1.75 | C16581 | C16581 | Nanjing Extension Microelectronics | TP4056-42-ESOP8 |  |  |  | 0.2578
13 | 1 | IC2 | LM393DR2G | LM393DR2G:LM393DR2G | LMS393DRG:SOIC127P600X175-8N | http://www.onsemi.com/pub/Collateral/LM393-D.PDF |  | LM393DR2G | https://www.arrow.com/en/products/lm393dr2g/on-semiconductor?region=europe | LM393DR2G, Dual Comparator Open Collector 1.3??s 12 V, 15 V, 18 V, 24 V, 28 V, 3 V, 5 V, 9 V 8-Pin SOIC N |  | 1.75 | C7955 | C7955 | ON Semiconductor | LM393DR2G | 863-LM393DR2G | https://www.mouser.co.uk/ProductDetail/onsemi/LM393DR2G?qs=2OtswVQKCOG5xGitOOiP7w%3D%3D |  | 0.1466
14 | 1 | IC3 | AT24C256C-SSHL-T | AT24C256C-SSHL-T:AT24C256C-SSHL-T | 3088_uC:SOIC127P600X175-8N |  |  |  |  |  |  |  | C6482 | C6482 |  |  |  |  |  | 1.5556
15 | 1 | IC4 | TXS0108EPWR | TXS0108EPWR:TXS0108EPWR | 3088_uC:SOP65P640X120-20N | http://www.ti.com/lit/ds/symlink/txs0108e.pdf |  | TXS0108EPWR | https://www.arrow.com/en/products/txs0108epwr/texas-instruments?region=nac | TXS0108EPWR, Voltage Level Translator, Open Drain 1.2 3.6 V, 1.65 5.5 V 20-Pin TSSOP |  | 1.2 | C17206 | C17206 | Texas Instruments | TXS0108EPWR | 595-TXS0108EPWR | https://www.mouser.co.uk/ProductDetail/Texas-Instruments/TXS0108EPWR?qs=IUbkBnfnSQLgiWtCbWtYOw%3D%3D |  | 1.4979
16 | 4 | J1, J2, J3, J4 | Conn_01x33_Female | Connector:Conn_01x33_Female | Connector_PinHeader_2.54mm:PinHeader_1x33_P2.54mm_Vertical | ~ | C12345 (example) |  |  |  |  |  |  | C1234 (example) |  |  |  |  | DNP | 0
17 | 1 | J5 | MICROXNJ | MICROXNJ:MICROXNJ | 3088_power:SHOUHAN_MICROXNJ | https://datasheet.lcsc.com/szlcsc/1912111437_SHOU-HAN-MicroXNJ_C404969.pdf |  |  |  | MICRO-USB-SMD_MICROXNJ |  | 2.425 | C404969 | C404969 | Shou Han | MICROXNJ |  |  |  | 0.6496
18 | 8 | J6, J7, J8, J9, J10, J11, J12, J13 | Conn_01x02_Male | Connector:Conn_01x02_Male | conn_Molex_01_02_vert:53398-0271 | ~ |  |  |  |  |  |  | C122410 | C122410 |  |  |  |  |  | 0.7097
19 | 1 | Q1 | MMBT3904 | Transistor_BJT:MMBT3904 | Package_TO_SOT_SMD:SOT-23 | https://www.onsemi.com/pub/Collateral/2N3903-D.PDF |  |  |  |  |  |  | C20526 | C20526 |  |  |  |  |  | 0.0143
20 | 1 | Q2 | AO3401A | Transistor_FET:AO3401A | AO3401A:SOT95P280X125-3N | http://www.aosmd.com/pdfs/datasheet/AO3401A.pdf |  |  |  |  |  |  | C15127 | C15127 |  |  |  |  |  | 0.1774
21 | 9 | R1, R2, R3, R4, R5, R10, R11, R12, R16 | 0R | Device:R_Small_US | 0R:RESC2013X65N | https://datasheet.lcsc.com/lcsc/2110251730_UNI-ROYAL-Uniroyal-Elec-0402WGF0000TCE_C17168.pdf |  |  |  |  |  |  | C17477 | C17477 |  |  |  |  |  | 0.0024
22 | 2 | R6, R7 | 4.7k | Device:R_Small_US | 4k7:RESC2013X65N | https://datasheet.lcsc.com/lcsc/2110251730_UNI-ROYAL-Uniroyal-Elec-0402WGF0000TCE_C17168.pdf |  |  |  |  |  |  | C17673 | C17673 |  |  |  |  |  | 0.0027
23 | 3 | R8, R9, R14 | 1k | Device:R_Small_US | 1k:RESC1608X55N | ~ |  |  |  |  | $0.0007 |  | C21190 | C21190 |  |  |  |  |  | 0.0011
24 | 1 | R13 | 1k2 | Device:R_Small_US | 1k:RESC1608X55N | ~ |  |  |  |  |  |  | C22765 | C22765 |  |  |  |  |  | 0.0014
25 | 1 | R15 | 10k | Device:R_Small_US | 10k:RESC1005X40N | ~ |  |  |  |  | $0.0007 |  | C25905 | C25905 |  |  |  |  |  | 0.0007
26 | 2 | R17, R18 | 1k | Device:R | 1k:RESC1608X55N | ~ |  |  |  |  |  |  | C21190 | C21190 |  |  |  |  |  | 0.0011
27 | 2 | R19, R20 | 4.7k | 0402WGF4701TCE:0402WGF4701TCE | 4k7:RESC2013X65N | https://datasheet.lcsc.com/szlcsc/Uniroyal-Elec-0402WGF4701TCE_C25900.pdf |  |  |  | Chip Resistor - Surface Mount 4.7KOhms +/-1% 1/16W 0402 RoHS |  | 0.4 |  |  | UNI-ROYAL(Uniroyal Elec) | 0402WGF4701TCE
28 | 4 | R21, R22, R23, R24 | 1.5k | 0402WGF4701TCE:0402WGF4701TCE | 4k7:RESC2013X65N | https://datasheet.lcsc.com/szlcsc/Uniroyal-Elec-0402WGF4701TCE_C25900.pdf |  |  |  | Chip Resistor - Surface Mount 4.7KOhms +/-1% 1/16W 0402 RoHS |  | 0.4 | C25867 | C25867 | UNI-ROYAL(Uniroyal Elec) | 0402WGF4701TCE |  |  |  | 0.0009
29 | 11 | TP1, TP2, TP3, TP4, TP5, TP6, TP7, TP8, TP9, TP10, TP11 | TestPoint | Connector:TestPoint | TestPoint:TestPoint_Pad_D2.0mm | ~
30 | 1 | U1 | HT75xx-1-SOT89 | Regulator_Linear:HT75xx-1-SOT89 | Package_TO_SOT_SMD:SOT-89-3 | https://www.holtek.com/documents/10179/116711/HT75xx-1v250.pdf |  |  |  |  |  |  | C14289 | C14289 |  |  |  |  |  | 0.2291
31 | 1 | U2 | DS18B20Z | Sensor_Temperature:DS18B20Z | Package_SO:SOIC-8_3.9x4.9mm_P1.27mm | http://datasheets.maximintegrated.com/en/ds/DS18B20.pdf |  |  |  |  |  |  | C695837 | C695837 |  |  |  |  |  | 1.1052
32 | 1 | U3 | ALS-PDIC15-21B/TR8 | Sensor_Proximity:TSSP58038SS1XB | ALS_Light:LED-SMD_1206-4P-L3.2-W1.5-TR | http://www.vishay.com/docs/82740/tssp58038ss1xb.pdf |  |  |  |  |  |  | C131243 | C131243 |  |  |  |  |  | 0.4279
33 | 1 | U4 | CH340G | Interface_USB:CH340G | 3088_uC:SOIC127P600X180-16N | http://www.datasheet5.com/pdf-local-2195953 |  |  |  |  |  |  | C14267 | C14267 |  |  |  |  |  | 0.5838
34 | 1 | Y1 | YSX321SL | YSX321SL:YSX321SL | 3088_uC:YSX321SL | https://datasheet.lcsc.com/szlcsc/YSX321SL-30MHZ-10PF-8PPM_C70576.pdf |  |  |  | Crystal |  | 0.8 | C9002 | C9002 | YXC | YSX321SL |  |  |  | 0.1054

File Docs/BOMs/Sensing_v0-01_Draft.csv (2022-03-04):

Collated Components:
Item | Qty | Reference(s) | Value | LibPart | Footprint | Datasheet | Price
1 | 1 | C | 10uF | Device:C_Small |  | ~ | $0,3029
2 | 1 | R | 10K | Device:R_Small_US |  | ~ | $0,1403
3 | 1 | R | 10K | Device:R |  | ~ | $0,1403
4 | 1 | U3 | DS18B20Z | Sensor_Temperature:DS18B20Z | Package_SO:SOIC-8_3.9x4.9mm_P1.27mm | http://datasheets.maximintegrated.com/en/ds/DS18B20.pdf | $1,1052
5 | 1 | U4 | ALS-PDIC15-21B/TR8 | Sensor_Proximity:TSSP58038SS1XB | OptoDevice:Vishay_MINICAST-3Pin | http://www.vishay.com/docs/82740/tssp58038ss1xb.pdf | $0,4279
Total Price | $2,1166

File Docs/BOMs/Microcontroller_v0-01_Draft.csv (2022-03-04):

Column1 | Column2 | Column3 | Column4 | Column5 | Column6 | Column7 | Column8
Source: | D:\UCT2022\EEE3088F\EEE3088F_HAT\PCB\main\microcontroller_interfacing.kicad_sch
Date: | 04 Mar 2022 14:13:17
Tool: | Eeschema (6.0.2)
Generator: | D:\6.0\bin\scripting\plugins/bom_csv_grouped_by_value.py
Component Count: | 9
Collated Components:
Item | Qty | Reference(s) | Value | LibPart | Footprint | Datasheet
1 | 1 | C1 | 0.1u | pspice:CAP |  | ~ | $0.011
2 | 1 | C2 | 47nF | pspice:CAP |  | ~ | $0.011
3 | 2 | C3, C4 | 22p | pspice:CAP |  | ~ | 0.011 x 2
4 | 1 | IC1 | M24C02-WMN6TP | M24C02-WMN6TP:M24C02-WMN6TP |  |  | $0.1554
5 | 2 | R1, R2 | 4.7k | Device:R_US |  | ~ | $0.0083 x 2
6 | 1 | U1 | CH340G | Interface_USB:CH340G | Package_SO:SOIC-16_3.9x9.9mm_P1.27mm | http://www.datasheet5.com/pdf-local-2195953 | 3.6029$
7 | 1 | Y1 | Crystal | Device:Crystal |  | ~ | $0.4418

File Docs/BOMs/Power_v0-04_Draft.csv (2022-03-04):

Item | Quantity | Reference | Value | LibPart | Footprint | Datasheet | Alt_LCSC | Description | Height | LCSC | Manufacturer_Name | Manufacturer_Part_Number | Populate | Price
1 | 1 | BT1 | 18650 Battery | Device:Battery_Cell |  | ~ |  |  |  |  |  |  | DNP | $-
2 | 2 | C1 C2 | 10uF | Device:C_Small |  | ~ |  |  |  |  |  |  |  | $0,2292
3 | 1 | C3 | C_Small | Device:C_Small |  | ~ |  |  |  |  |  |  |  | $0,1146
4 | 1 | D1 | Green LED | Device:LED |  | ~ |  |  |  |  |  |  |  | $0,0314
5 | 1 | D2 | Red LED | Device:LED |  | ~ |  |  |  |  |  |  |  | $0,0088
6 | 2 | D3, D5 | D_Zener | Device:D_Zener |  | ~ |  |  |  |  |  |  |  | $0,0386
7 | 1 | D4 | White LED | Device:LED |  | ~ |  |  |  |  |  |  |  | $0,0147
8 | 1 | IC1 | TP4056-42-ESOP8 | TP4056:TP4056-42-ESOP8 | SOIC127P600X175-9N | https://datasheet.lcsc.com/szlcsc/1906261508_Nanjing-Extension-Microelectronics-TP4056-42-ESOP8_C16581.pdf |  | PMIC - Battery Management ESOP-8 RoHS | 1.75 |  | Nanjing Extension Microelectronics | TP4056-42-ESOP8 |  | $0,2523
9 | 1 | IC2 | AMS1117-3.3 | AMS1117-3.3V:AMS1117-3.3 | SOT229P700X180-4N | https://datasheet.datasheetarchive.com/originals/distributors/Datasheets-28/DSA-550594.pdf |  | Descriptions of ams AMS1117-3.3 provided by its distributors. | 1.8 |  | Advanced | AMS1117-3.3 |  | $0,1795
10 | 1 | IC3 | 74HC04D,653 | 74HC04D-653:74HC04D,653 | SOIC127P600X175-14N | https://assets.nexperia.com/documents/data-sheet/74HC_HCT04.pdf |  | 74HC(T)04 - Hex inverter@en-us | 1.75 |  | Nexperia | 74HC04D,653 |  | $0,2479
11 | 2 | J1, J4 | Conn_01x33_Female | Connector:Conn_01x33_Female | Connector_PinHeader_2.54mm:PinHeader_1x33_P2.54mm_Vertical | ~ |  |  |  |  |  |  | DNP | $-
12 | 2 | J2, J3 | Conn_01x33_Female | Connector:Conn_01x33_Female | Connector_PinSocket_2.54mm:PinSocket_1x33_P2.54mm_Vertical | ~ | C12345 (example) |  |  | C1234 (example) |  |  | DNP | $-
13 | 1 | J5 | MICROXNJ | MICROXNJ:MICROXNJ | MICROXNJ | https://datasheet.lcsc.com/szlcsc/1912111437_SHOU-HAN-MicroXNJ_C404969.pdf |  | MICRO-USB-SMD_MICROXNJ | 2.425 |  | Shou Han | MICROXNJ |  | $3,0480
14 | 2 | M1, M2 | MPMOS | pspice:MPMOS |  | ~ |  |  |  |  |  |  |  | $0,4076
15 | 2 | M3, M4 | MNMOS | pspice:MNMOS |  | ~ |  |  |  |  |  |  |  | $0,4076
16 | 1 | Q1 | Q_PNP_BCE | Device:Q_PNP_BCE |  | ~ |  |  |  |  |  |  |  | $0,0905
17 | 1 | Q2 | Q_PMOS_GDS | Device:Q_PMOS_GDS |  | ~ |  |  |  |  |  |  |  | $0,2038
18 | 1 | Q3 | Q_PMOS_DGS | Device:Q_PMOS_DGS |  | ~ |  |  |  |  |  |  |  | $0,2038
19 | 1 | Q4 | 2N3904 | Transistor_BJT:2N3904 | Package_TO_SOT_THT:TO-92_Inline | https://www.onsemi.com/pub/Collateral/2N3903-D.PDF |  |  |  |  |  |  |  | $3,0158
20 | 1 | Q5 | Q_NMOS_DSG | Device:Q_NMOS_DSG |  | ~ |  |  |  |  |  |  |  | $0,2038
21 | 1 | R1 | 0.4Î© | Device:R_Small_US |  | ~ |  |  |  |  |  |  |  | $0,0013
22 | 6 | R2, R6, R7, R8, R9, R12 | 10kÎ© | Device:R_Small_US |  | ~ |  |  |  |  |  |  |  | $0,0072
23 | 8 | R3, R4, R10, R11, R13, R14, R15, R16 | 1kÎ© | Device:R_Small_US |  | ~ |  |  |  |  |  |  |  | $0,1920
24 | 1 | R5 | R | Device:R_Small_US |  | ~ |  |  |  |  |  |  |  | $0,0012
25 | 1 | U1 | LM393 | Comparator:LM393 |  | http://www.ti.com/lit/ds/symlink/lm393.pdf |  |  |  |  |  |  |  | $0,1466
26 | 1 | U2 | LT1492 | Amplifier_Operational:LT1492 |  | https://www.analog.com/media/en/technical-documentation/data-sheets/14923f.pdf |  |  |  |  |  |  |  | $0,2405
 |  |  |  |  |  |  |  |  |  |  |  |  |  | $9,2867
Total Price |  |  | $9,2867

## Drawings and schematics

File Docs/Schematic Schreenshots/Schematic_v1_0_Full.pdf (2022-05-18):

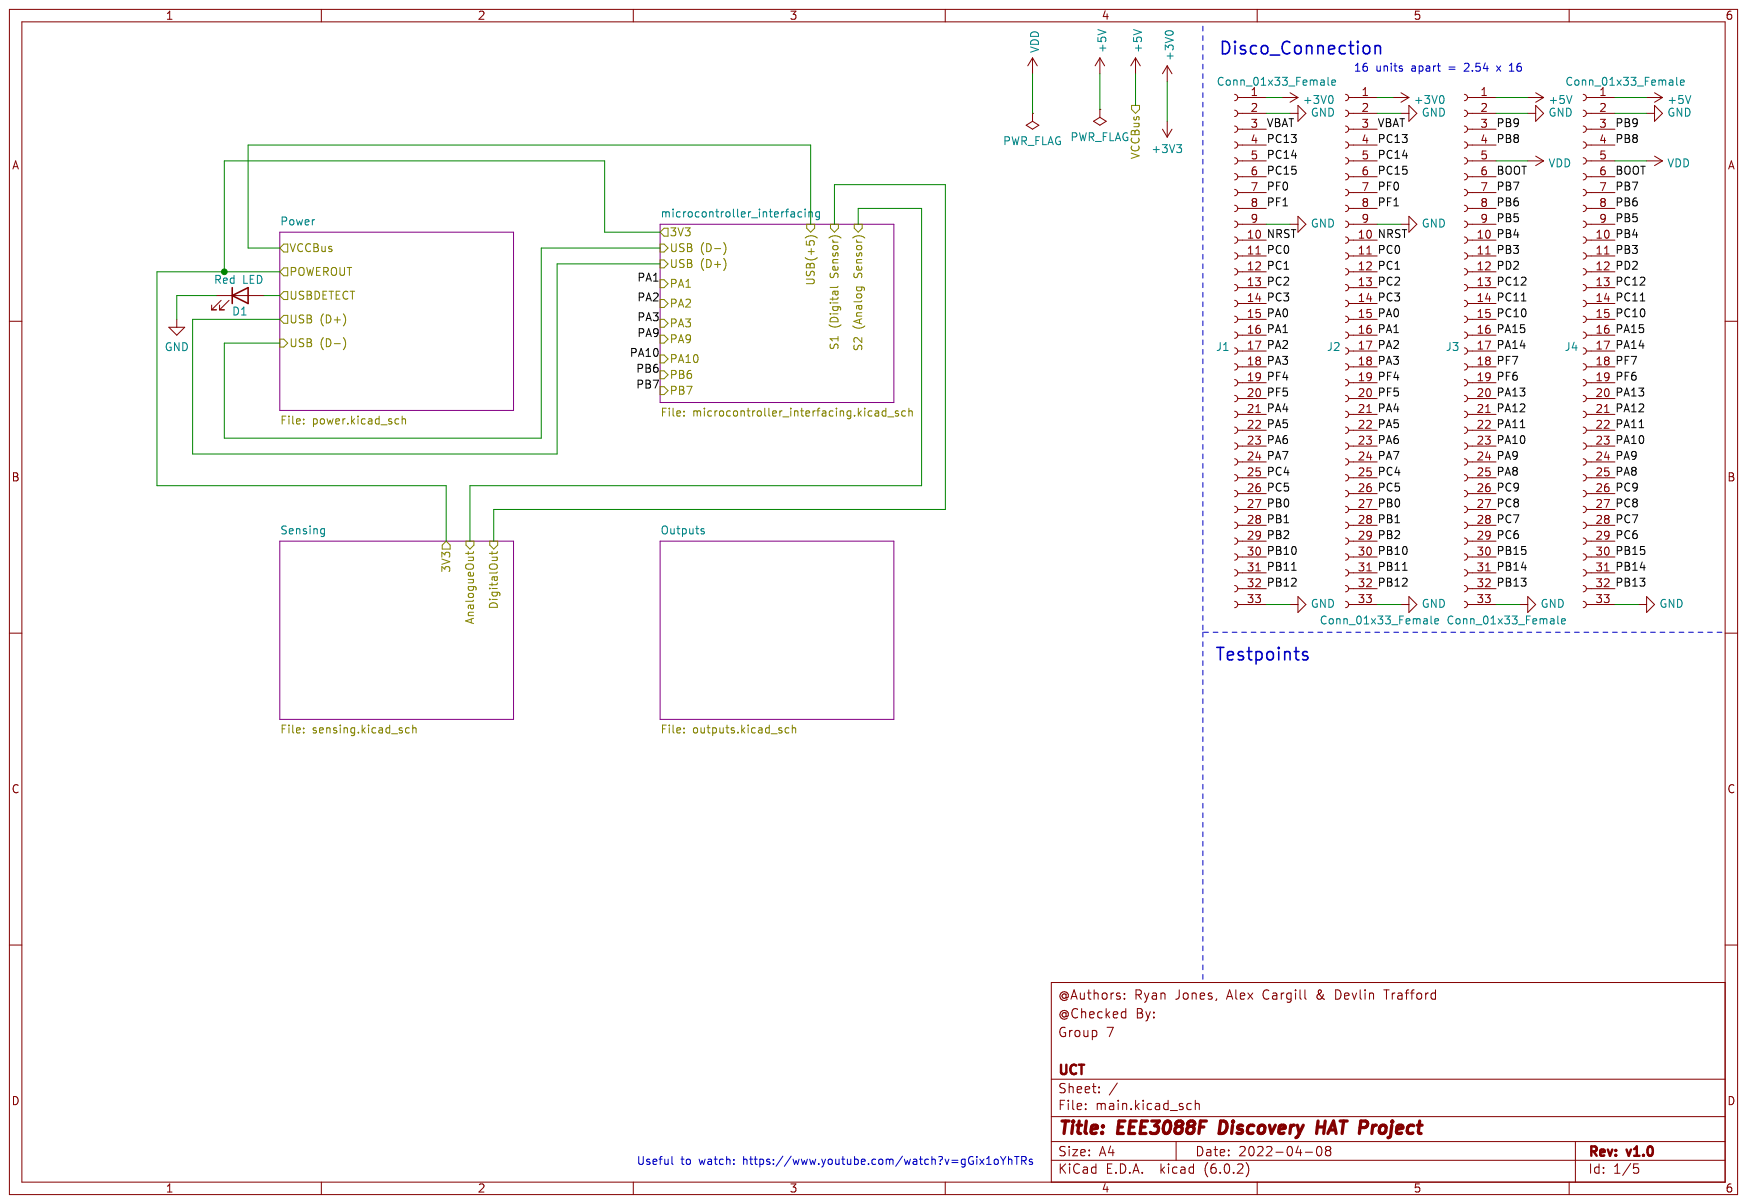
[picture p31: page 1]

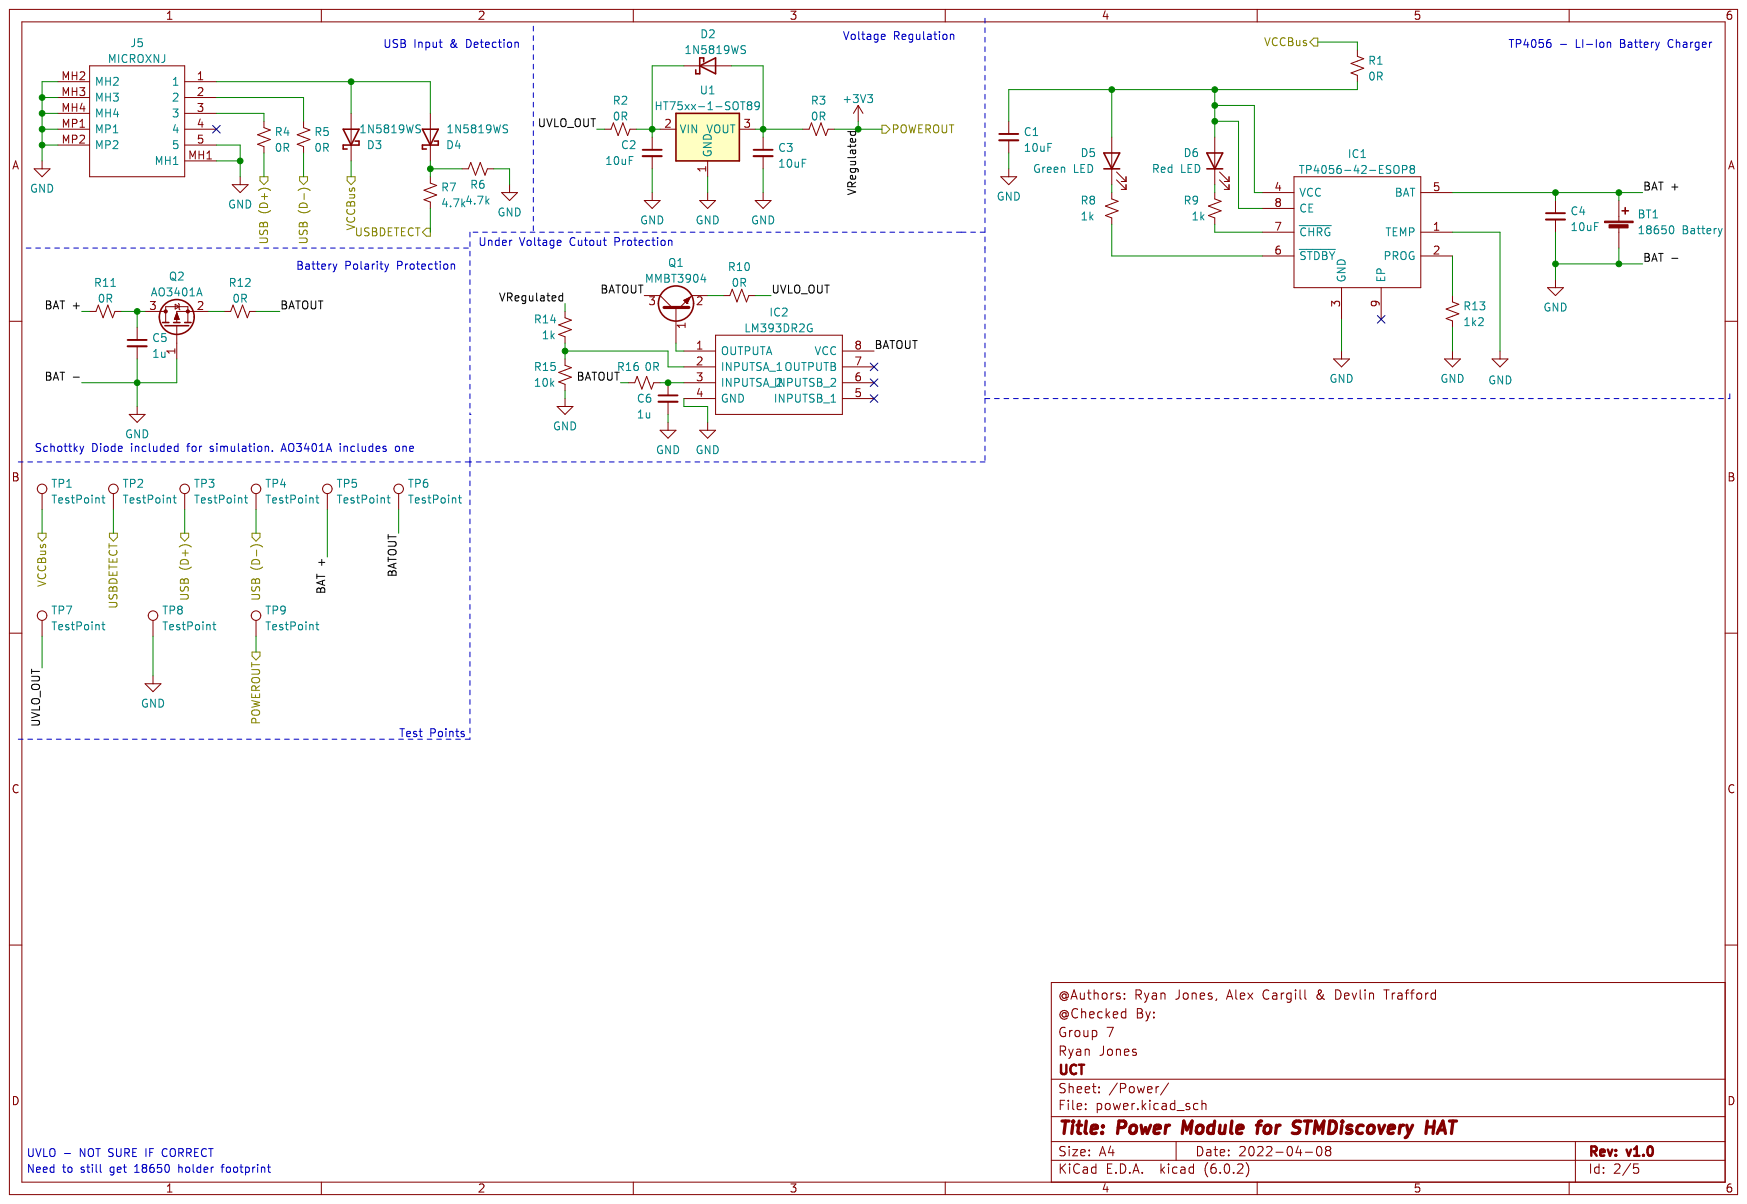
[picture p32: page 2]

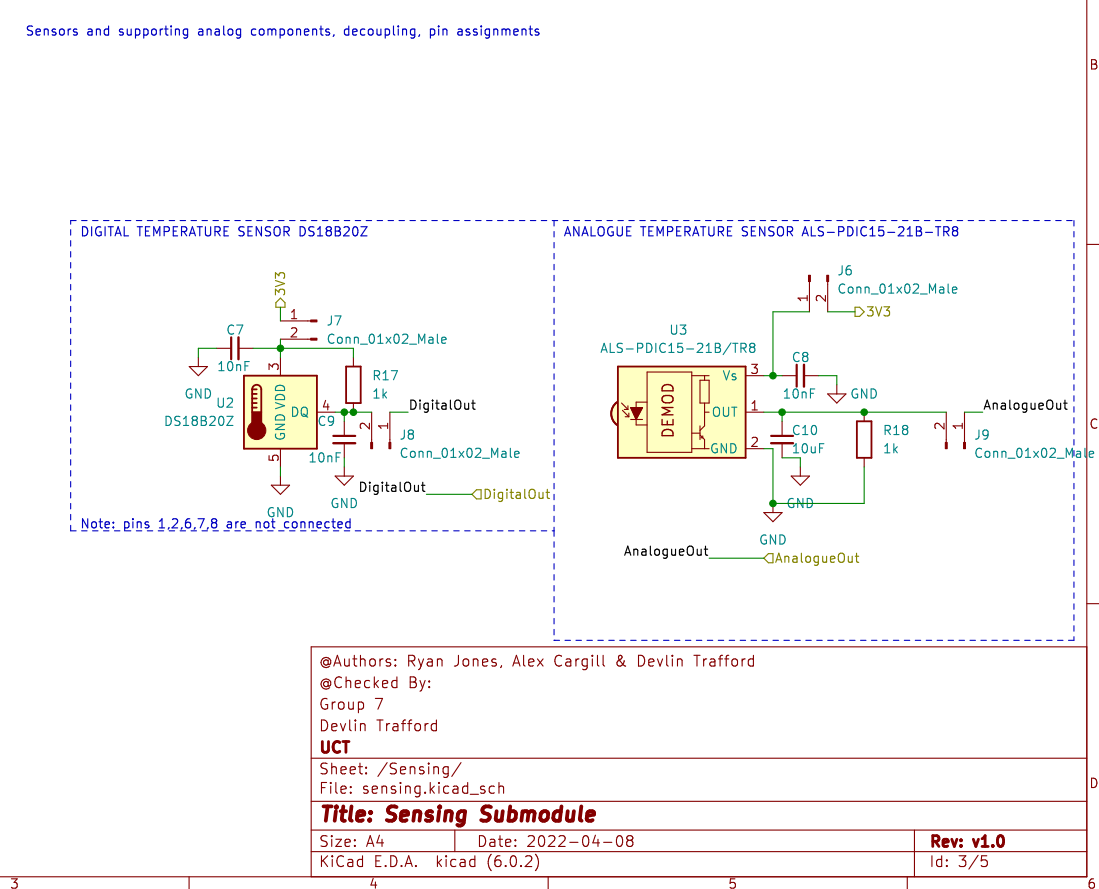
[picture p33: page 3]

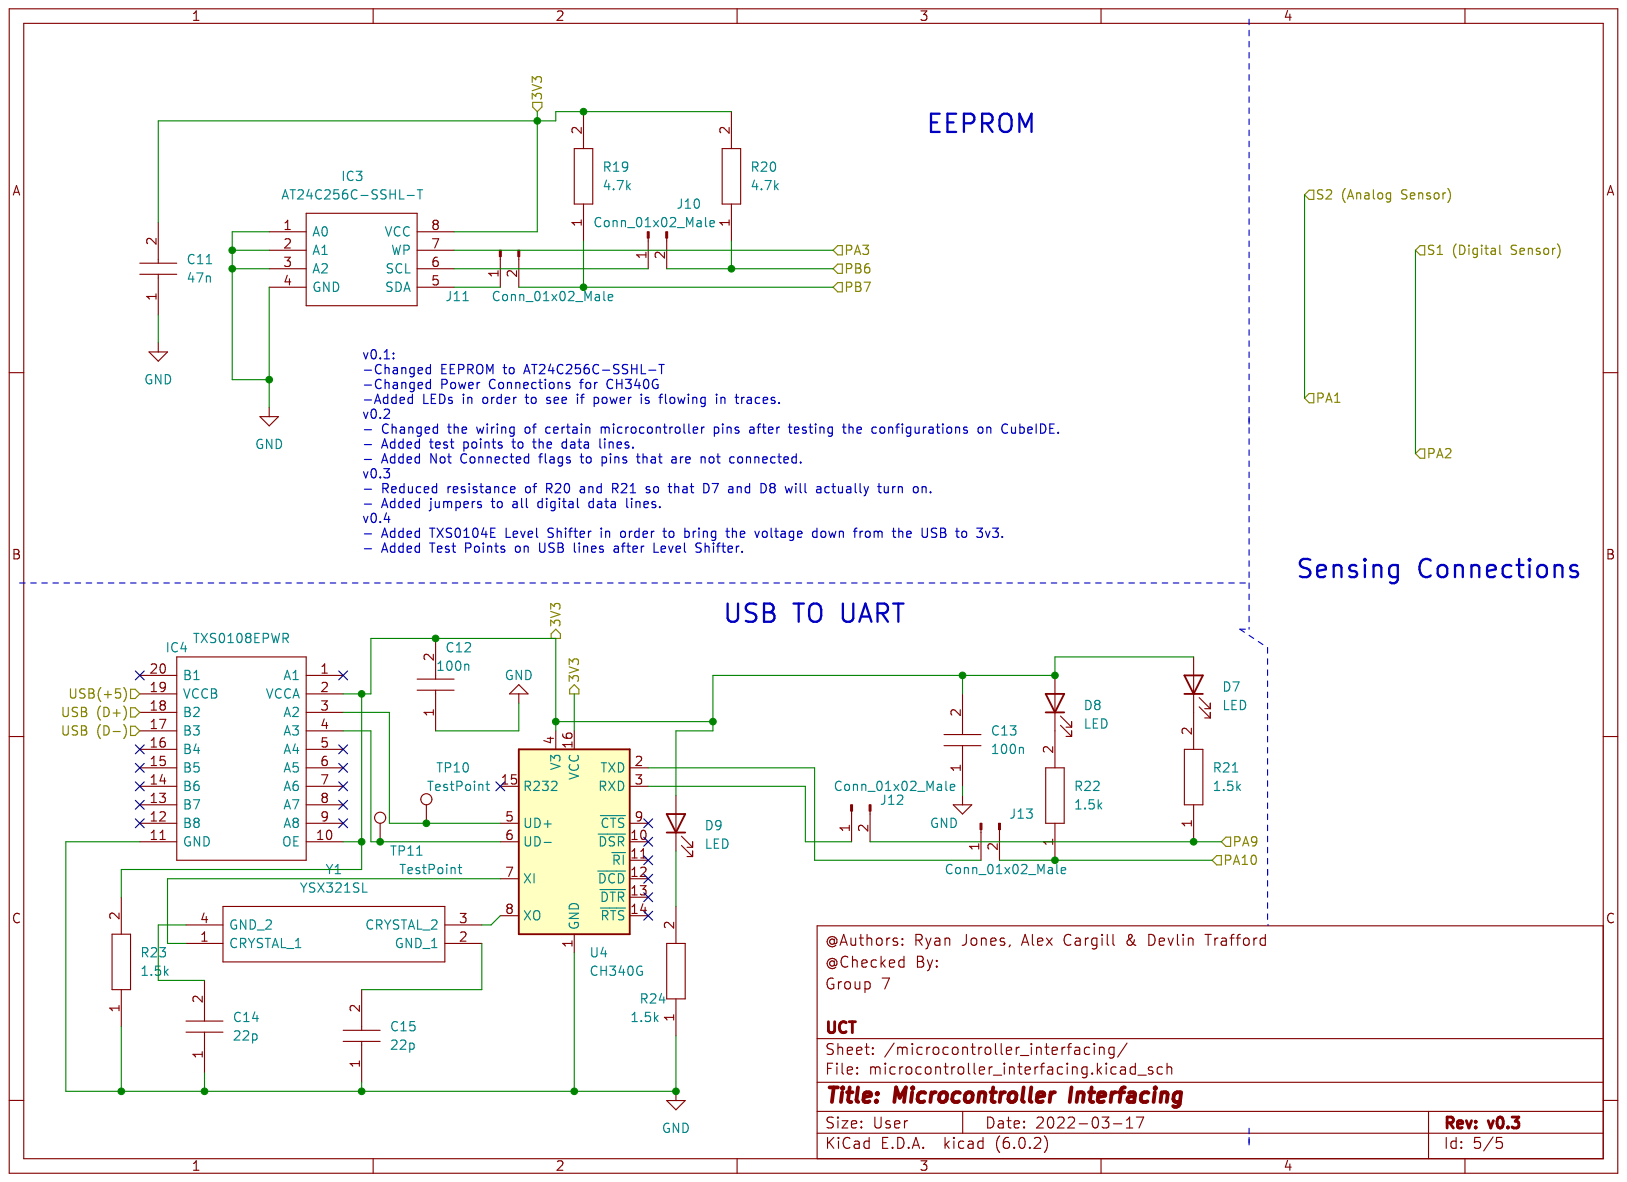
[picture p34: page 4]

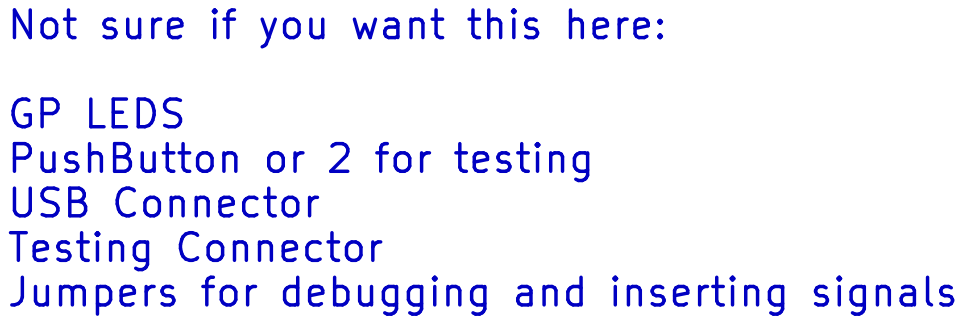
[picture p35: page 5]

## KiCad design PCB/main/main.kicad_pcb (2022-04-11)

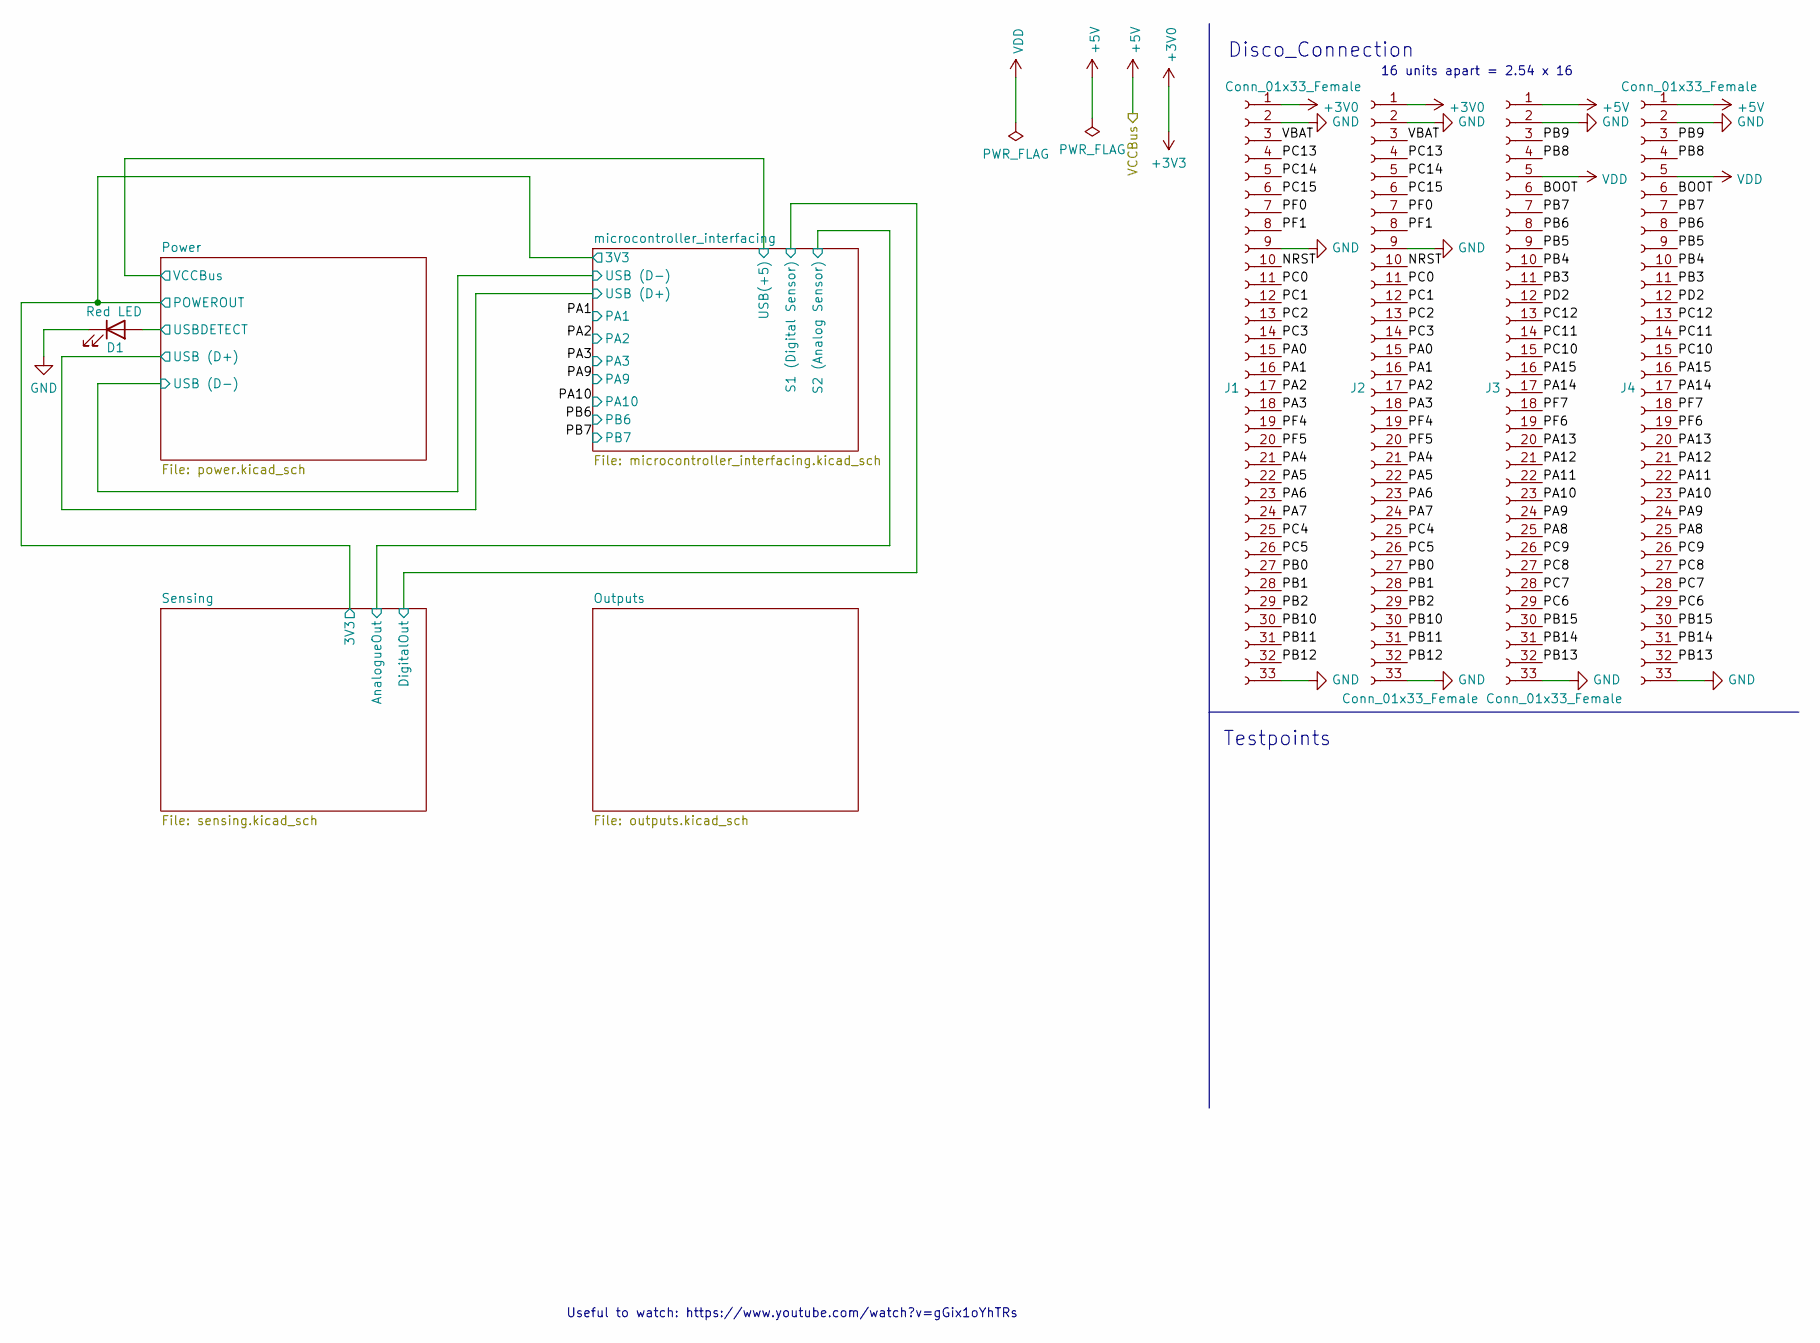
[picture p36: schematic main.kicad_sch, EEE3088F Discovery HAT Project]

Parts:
D1: Red LED; LEDC1608X70N; JLC Part Number C84256
J1, J4: Conn_01x33_Female; PinHeader_1x33_P2.54mm_Vertical
J2, J3: Conn_01x33_Female; PinSocket_1x33_P2.54mm_Vertical; LCSC C1234 (example)

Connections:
+3V0: J1.1, J2.1; also elsewhere on the board
+5V: J3.1, J4.1; also elsewhere on the board
/BOOT: J3.6, J4.6
/NRST: J1.10, J2.10
/PA0: J1.15, J2.15
/PA1: J1.16, J2.16; also elsewhere on the board
/PA2: J1.17, J2.17; also elsewhere on the board
/PA3: J1.18, J2.18; also elsewhere on the board
/PA4: J1.21, J2.21
/PA5: J1.22, J2.22
/PA6: J1.23, J2.23
/PA7: J1.24, J2.24
/PA8: J3.25, J4.25
/PA9: J3.24, J4.24; also elsewhere on the board
/PA10: J3.23, J4.23; also elsewhere on the board
/PA11: J3.22, J4.22
/PA12: J3.21, J4.21
/PA13: J3.20, J4.20
/PA14: J3.17, J4.17
/PA15: J3.16, J4.16
/PB0: J1.27, J2.27
/PB1: J1.28, J2.28
/PB2: J1.29, J2.29
/PB3: J3.11, J4.11
/PB4: J3.10, J4.10
/PB5: J3.9, J4.9
/PB6: J3.8, J4.8; also elsewhere on the board
/PB7: J3.7, J4.7; also elsewhere on the board
/PB8: J3.4, J4.4
/PB9: J3.3, J4.3
/PB10: J1.30, J2.30
/PB11: J1.31, J2.31
/PB12: J1.32, J2.32
/PB13: J3.32, J4.32
/PB14: J3.31, J4.31
/PB15: J3.30, J4.30
/PC0: J1.11, J2.11
/PC1: J1.12, J2.12
/PC2: J1.13, J2.13
/PC3: J1.14, J2.14
/PC4: J1.25, J2.25
/PC5: J1.26, J2.26
/PC6: J3.29, J4.29
/PC7: J3.28, J4.28
/PC8: J3.27, J4.27
/PC9: J3.26, J4.26
/PC10: J3.15, J4.15
/PC11: J3.14, J4.14
/PC12: J3.13, J4.13
/PC13: J1.4, J2.4
/PC14: J1.5, J2.5
/PC15: J1.6, J2.6
/PD2: J3.12, J4.12
/PF0: J1.7, J2.7
/PF1: J1.8, J2.8
/PF4: J1.19, J2.19
/PF5: J1.20, J2.20
/PF6: J3.19, J4.19
/PF7: J3.18, J4.18
/Power/USBDETECT: D1.2 (A); also elsewhere on the board
/VBAT: J1.3, J2.3
GND: D1.1 (K), J1.2, J1.9, J1.33, J2.2, J2.9, J2.33, J3.2, J3.33, J4.2, J4.33; also elsewhere on the board
VDD: J3.5, J4.5

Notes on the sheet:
Useful to watch: https://www.youtube.com/watch?v=gGix1oYhTRs
16 units apart = 2.54 x 16
Disco_Connection
Testpoints

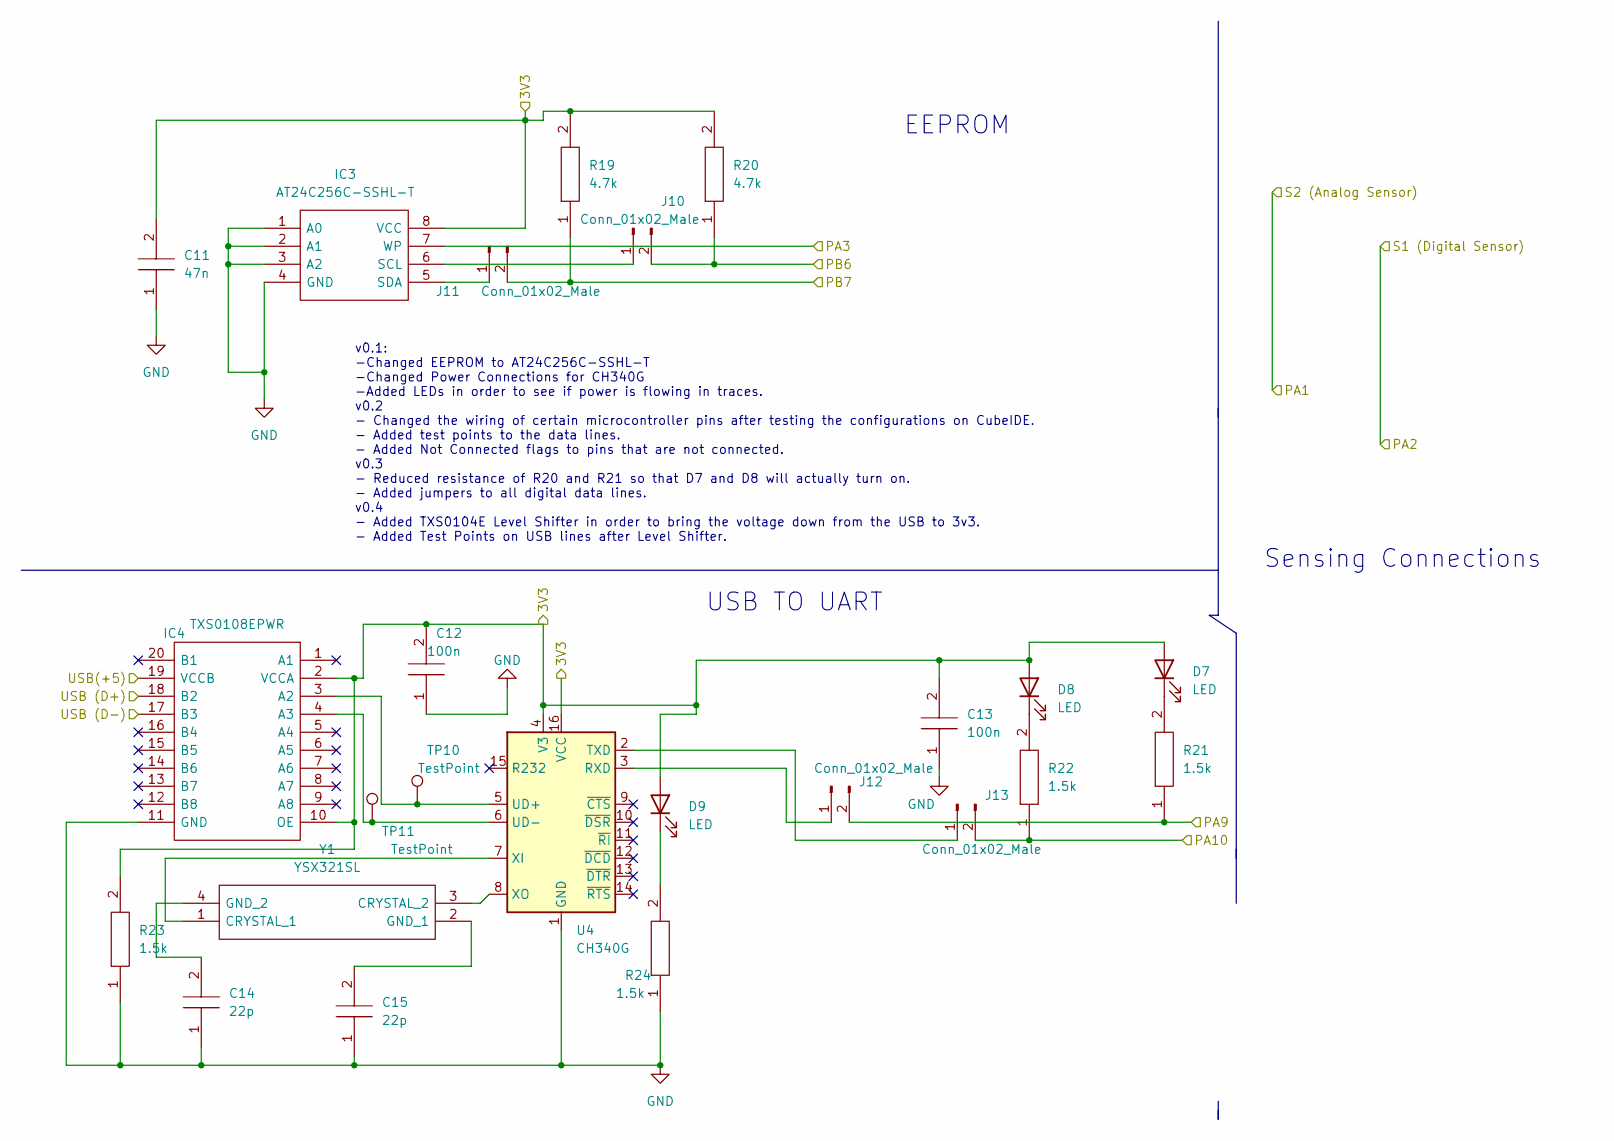
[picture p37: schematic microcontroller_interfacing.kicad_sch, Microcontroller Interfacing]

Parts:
C11: 47n; CAPC1608X90N; Manufacturer_Part_Number CL05B104KO5NNNC; Mouser Part Number 187-CL05B104KO5NNNC
C12, C13: 100n; C_0402_1005Metric; Manufacturer_Part_Number CL05B104KO5NNNC; Mouser Part Number 187-CL05B104KO5NNNC
C14, C15: 22p; CAPC1608X90N; Manufacturer_Part_Number CL05B104KO5NNNC; Mouser Part Number 187-CL05B104KO5NNNC
D7, D8, D9: LED; LED_0805_2012Metric; JLC Part Number C2286
IC3: AT24C256C-SSHL-T; SOIC127P600X175-8N; JLC Part Number C6482
IC4: TXS0108EPWR; SOP65P640X120-20N; Manufacturer_Part_Number TXS0108EPWR; Mouser Part Number 595-TXS0108EPWR
J10, J11, J12, J13: Conn_01x02_Male; 53398-0271; JLC Part Number C122410
R19, R20: 4.7k; RESC2013X65N; Manufacturer_Part_Number 0402WGF4701TCE
R21, R22, R23, R24: 1.5k; RESC2013X65N; Manufacturer_Part_Number 0402WGF4701TCE; JLC Part Number C25867
TP10, TP11: TestPoint; TestPoint_Pad_D2.0mm
U4: CH340G; SOIC127P600X180-16N; JLC Part Number C14267
Y1: YSX321SL; Manufacturer_Part_Number YSX321SL; JLC Part Number C9002

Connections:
+3V3: C11.2, C12.2, C13.2, D7.2 (A), D8.2 (A), D9.2 (A), IC3.8 (VCC), IC4.2 (VCCA), IC4.10 (OE), R19.2, R20.2, R23.2, U4.4 (V3), U4.16 (VCC); also elsewhere on the board
+5V: IC4.19 (VCCB); also elsewhere on the board
/PA3: IC3.7 (WP); also elsewhere on the board
/PA9: J12.2, R21.1; also elsewhere on the board
/PA10: J13.2, R22.1; also elsewhere on the board
/PB6: J10.2, R20.1; also elsewhere on the board
/PB7: J11.2, R19.1; also elsewhere on the board
/Power/USB (D+): IC4.18 (B2); also elsewhere on the board
/Power/USB (D-): IC4.17 (B3); also elsewhere on the board
GND: C11.1, C12.1, C13.1, C14.1, C15.1, IC3.1 (A0), IC3.2 (A1), IC3.3 (A2), IC3.4 (GND), IC4.11 (GND), R23.1, R24.1, U4.1 (GND); also elsewhere on the board
unnamed: C14.2, Y1.4 (GND_2)
unnamed: C15.2, Y1.2 (GND_1)
unnamed: D7.1 (K), R21.2
unnamed: D8.1 (K), R22.2
unnamed: D9.1 (K), R24.2
unnamed: IC3.5 (SDA), J11.1
unnamed: IC3.6 (SCL), J10.1
unnamed: IC4.3 (A2), TP10.1, U4.5 (UD+)
unnamed: IC4.4 (A3), TP11.1, U4.6 (UD-)
unnamed: J12.1, U4.3 (RXD)
unnamed: J13.1, U4.2 (TXD)
unnamed: U4.7 (XI), Y1.1 (CRYSTAL_1)
unnamed: U4.8 (XO), Y1.3 (CRYSTAL_2)

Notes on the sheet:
v0.1: -Changed EEPROM to AT24C256C-SSHL-T -Changed Power Connections for CH340G -Added LEDs in order to see if power is flowing in traces. v0.2 - Changed the wiring of certain microcontroller pins after testing the configurations on CubeIDE. - Added test points to the data lines. - Added Not Connec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
EEPROM
USB TO UART
Sensing Connections

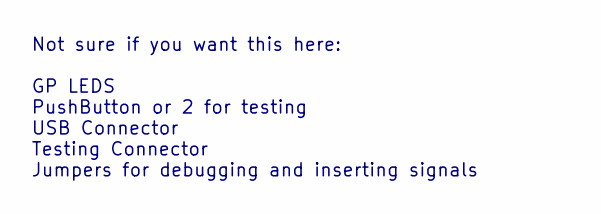
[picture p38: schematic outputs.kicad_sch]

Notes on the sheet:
Not sure if you want this here: GP LEDS PushButton or 2 for testing USB Connector Testing Connector Jumpers for debugging and inserting signals

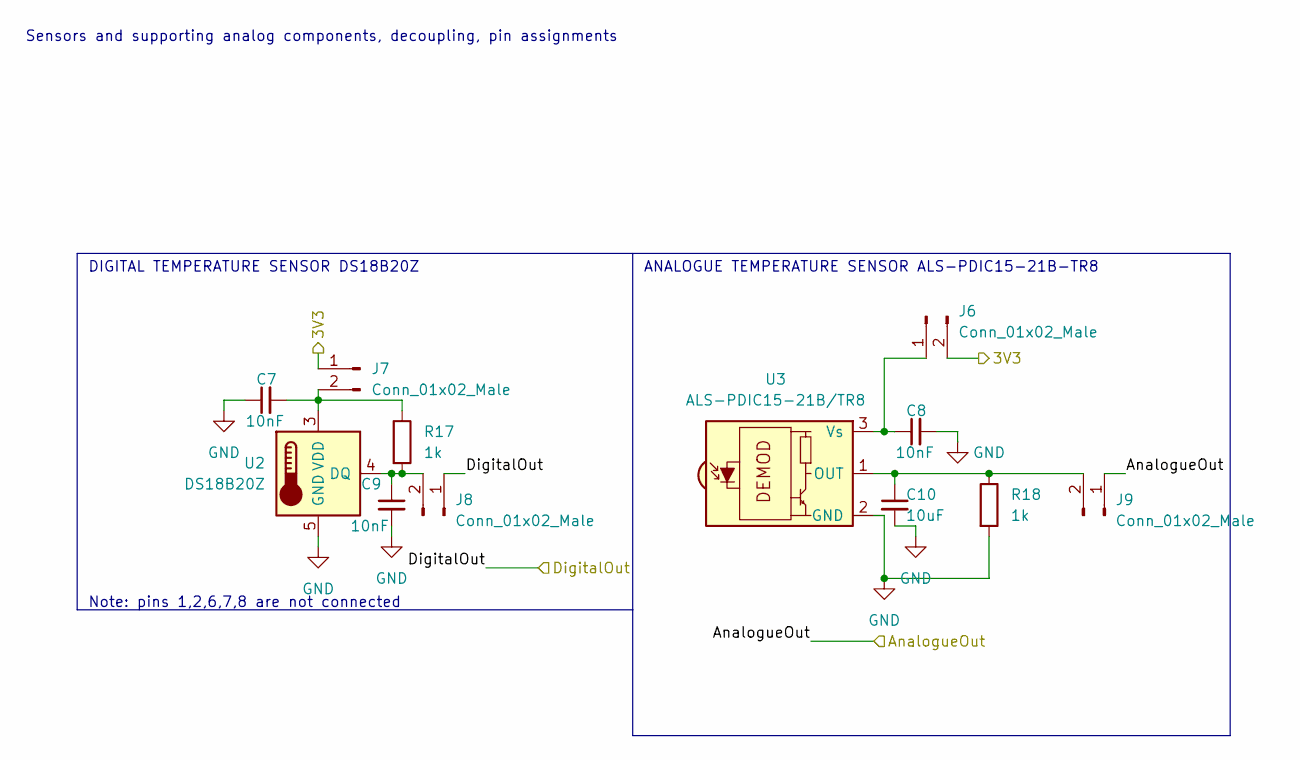
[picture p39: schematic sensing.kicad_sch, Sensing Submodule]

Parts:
C7, C8, C9: 10nF; C_0402_1005Metric; JLC Part Number C15195
C10: 10uF; CAPC2012X145N; JLC Part Number C19702
J6, J7, J8, J9: Conn_01x02_Male; 53398-0271; JLC Part Number C122410
R17, R18: 1k; RESC1608X55N; JLC Part Number C21190
U2: DS18B20Z; SOIC-8_3.9x4.9mm_P1.27mm; JLC Part Number C695837
U3: ALS-PDIC15-21B/TR8; LED-SMD_1206-4P-L3.2-W1.5-TR; JLC Part Number C131243

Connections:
+3V3: J6.2, J7.1; also elsewhere on the board
/PA1: J9.1; also elsewhere on the board
/PA2: J8.1; also elsewhere on the board
GND: C7.1, C8.2, C9.2, C10.2, R18.2, U2.5 (GND), U3.2 (GND); also elsewhere on the board
unnamed: C7.2, J7.2, R17.1, U2.3 (VDD)
unnamed: C8.1, J6.1, U3.3 (Vs)
unnamed: C9.1, J8.2, R17.2, U2.4 (DQ)
unnamed: C10.1, J9.2, R18.1, U3.1 (OUT)

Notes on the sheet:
ANALOGUE TEMPERATURE SENSOR ALS-PDIC15-21B-TR8
DIGITAL TEMPERATURE SENSOR DS18B20Z
Note: pins 1,2,6,7,8 are not connected
Sensors and supporting analog components, decoupling, pin assignments

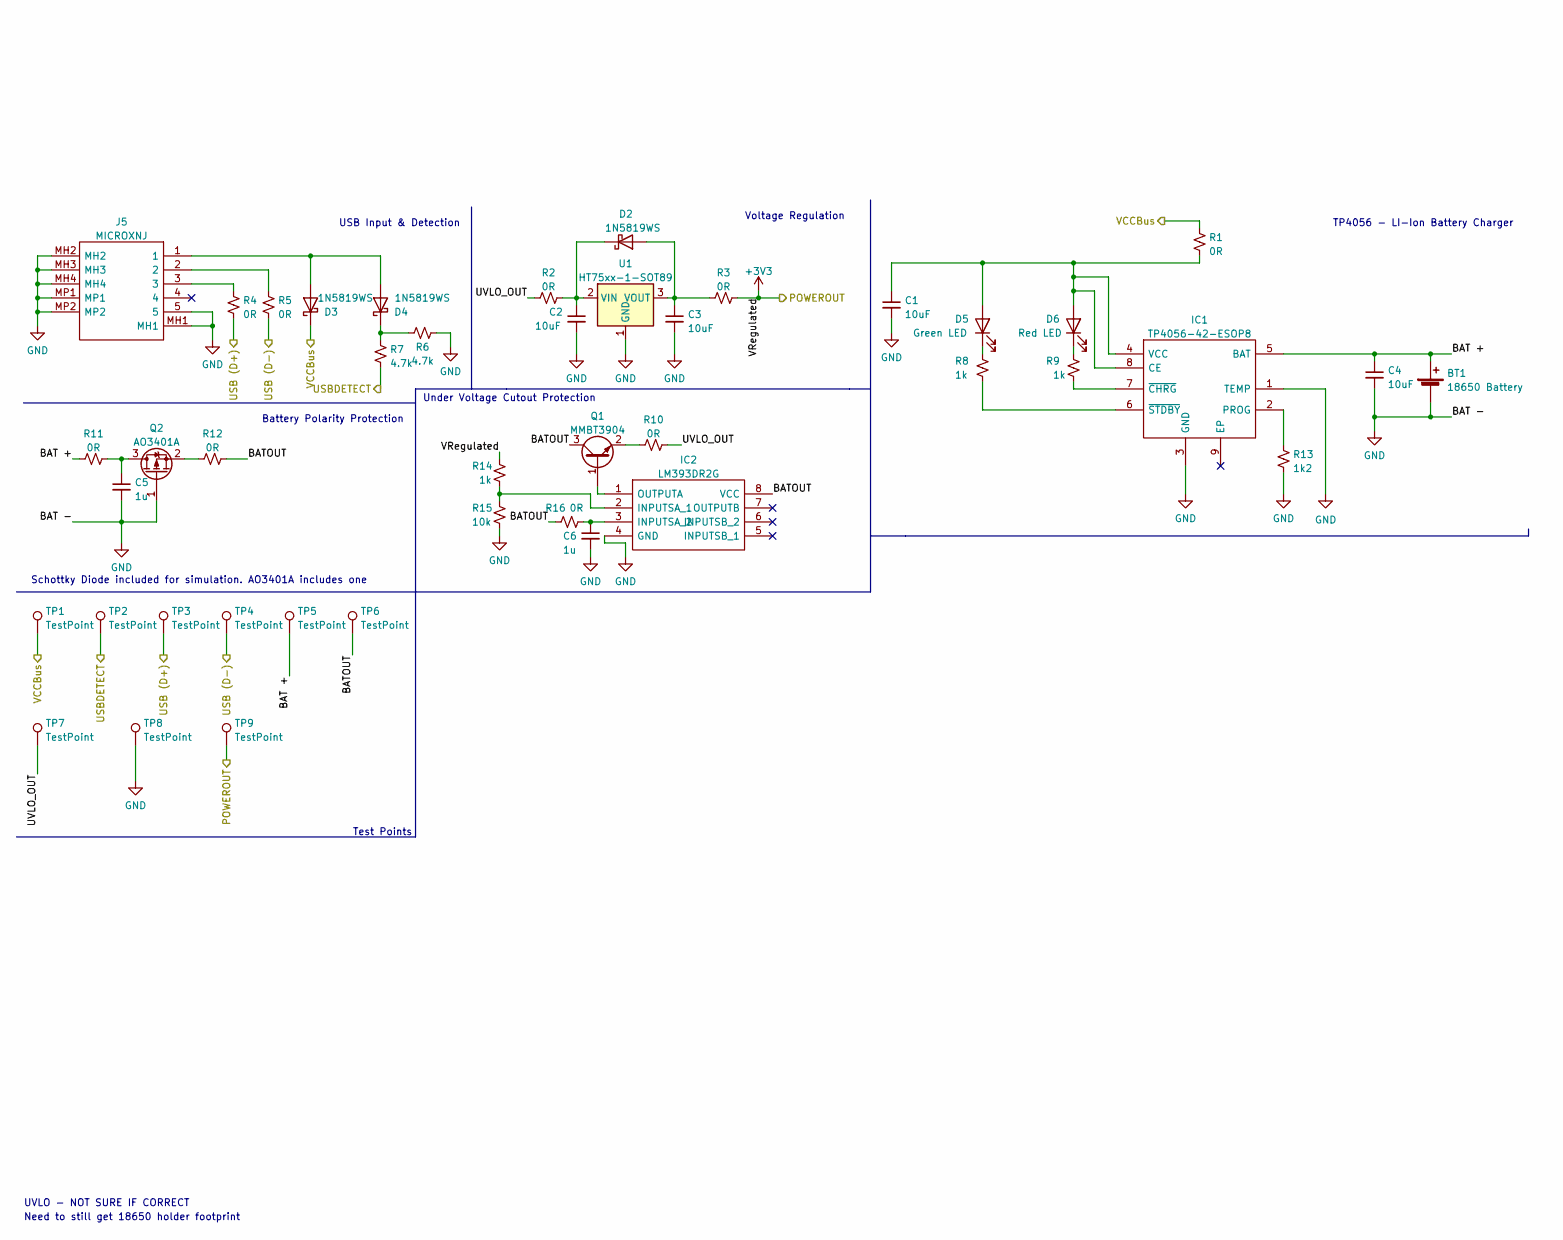
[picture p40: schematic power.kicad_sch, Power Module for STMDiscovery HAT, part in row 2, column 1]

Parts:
BT1: 18650 Battery; KEYSTONE-1042
C1, C2, C3, C4: 10uF; CAPC2012X145N; JLC Part Number C19702
C5, C6: 1u; CAPC1608X90N; JLC Part Number C52923
D2, D3, D4: 1N5819WS; D_SOD-323; JLC Part Number C191023
D5: Green LED; LEDC1608X50N; JLC Part Number C72043
D6: Red LED; LEDC1608X70N; JLC Part Number C84256
IC1: TP4056-42-ESOP8; SOIC127P600X175-9N; Manufacturer_Part_Number TP4056-42-ESOP8; JLC Part Number C16581
IC2: LM393DR2G; SOIC127P600X175-8N; Manufacturer_Part_Number LM393DR2G; Mouser Part Number 863-LM393DR2G
J5: MICROXNJ; SHOUHAN_MICROXNJ; Manufacturer_Part_Number MICROXNJ; JLC Part Number C404969
Q1: MMBT3904; SOT-23; JLC Part Number C20526
Q2: AO3401A; SOT95P280X125-3N; JLC Part Number C15127
R1, R2, R3, R4, R5, R10, R11, R12, R16: 0R; RESC2013X65N; JLC Part Number C17477
R6, R7: 4.7k; RESC2013X65N; JLC Part Number C17673
R8, R9, R14: 1k; RESC1608X55N; JLC Part Number C21190
R13: 1k2; RESC1608X55N; JLC Part Number C22765
R15: 10k; RESC1005X40N; JLC Part Number C25905
TP1, TP2, TP3, TP4, TP5, TP6, TP7, TP8, TP9: TestPoint; TestPoint_Pad_D2.0mm
U1: HT75xx-1-SOT89; SOT-89-3; JLC Part Number C14289

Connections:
+3V0: R3.1, R14.1, TP9.1; also elsewhere on the board
+5V: D3.1 (K), R1.2, TP1.1; also elsewhere on the board
/Power/BAT +: BT1.1 (+), C4.1, IC1.5 (BAT), R11.2, TP5.1
/Power/BATOUT: IC2.8 (VCC), Q1.3 (C), R12.1, R16.2, TP6.1
/Power/USB (D+): R4.1, TP3.1; also elsewhere on the board
/Power/USB (D-): R5.1, TP4.1; also elsewhere on the board
/Power/USBDETECT: R7.1, TP2.1; also elsewhere on the board
/Power/UVLO_OUT: R2.2, R10.1, TP7.1
GND: BT1.2 (-), C1.2, C2.2, C3.2, C4.2, C5.2, C6.2, IC1.1 (TEMP), IC1.3 (GND), IC2.4 (GND), J5.5, J5.MH1, J5.MH2, J5.MH3, J5.MH4, J5.MP1, J5.MP2, Q2.1 (G), R6.2, R13.2, R15.2, TP8.1, U1.1 (GND); also elsewhere on the board
unnamed: C1.1, D5.2 (A), D6.2 (A), IC1.4 (VCC), IC1.8 (CE), R1.1
unnamed: C2.1, D2.1 (K), R2.1, U1.2 (VIN)
unnamed: C3.1, D2.2 (A), R3.2, U1.3 (VOUT)
unnamed: C5.1, Q2.3 (D), R11.1
unnamed: C6.1, IC2.3 (INPUTSA_2), R16.1
unnamed: D3.2 (A), D4.2 (A), J5.1
unnamed: D4.1 (K), R6.1, R7.2
unnamed: D5.1 (K), R8.1
unnamed: D6.1 (K), R9.1
unnamed: IC1.2 (PROG), R13.1
unnamed: IC1.6 (~STDBY), R8.2
unnamed: IC1.7 (~CHRG), R9.2
unnamed: IC2.1 (OUTPUTA), Q1.1 (B)
unnamed: IC2.2 (INPUTSA_1), R14.2, R15.1
unnamed: J5.2, R5.2
unnamed: J5.3, R4.2
unnamed: Q1.2 (E), R10.2
unnamed: Q2.2 (S), R12.2

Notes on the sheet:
Battery Polarity Protection
USB Input & Detection
Voltage Regulation
TP4056 - LI-Ion Battery Charger
Under Voltage Cutout Protection
UVLO - NOT SURE IF CORRECT
Test Points
Check IC can take in ~4V
Schottky Diode included for simulation. AO3401A includes one
Need to still get 18650 holder footprint

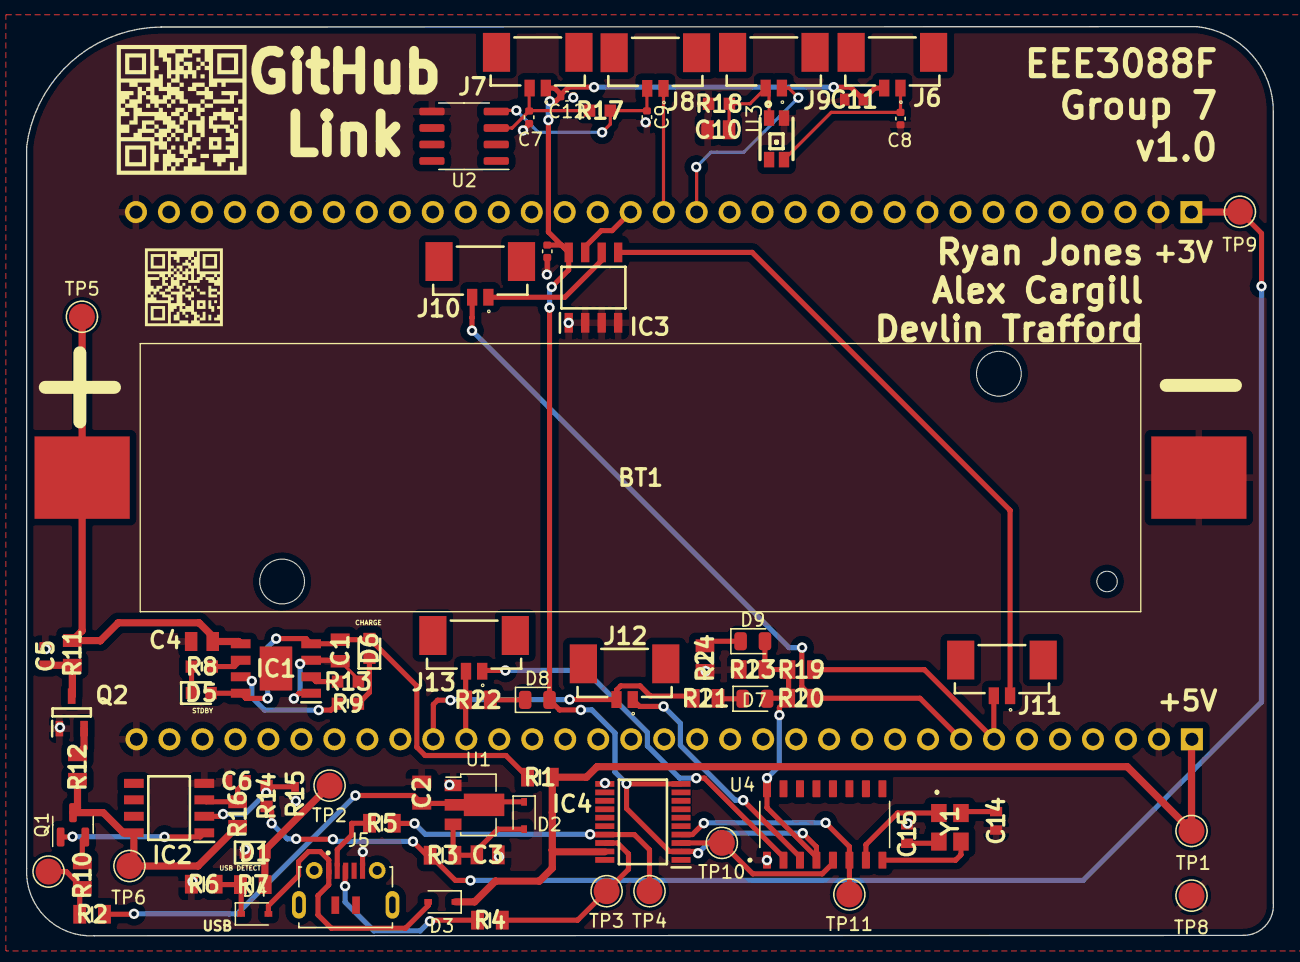
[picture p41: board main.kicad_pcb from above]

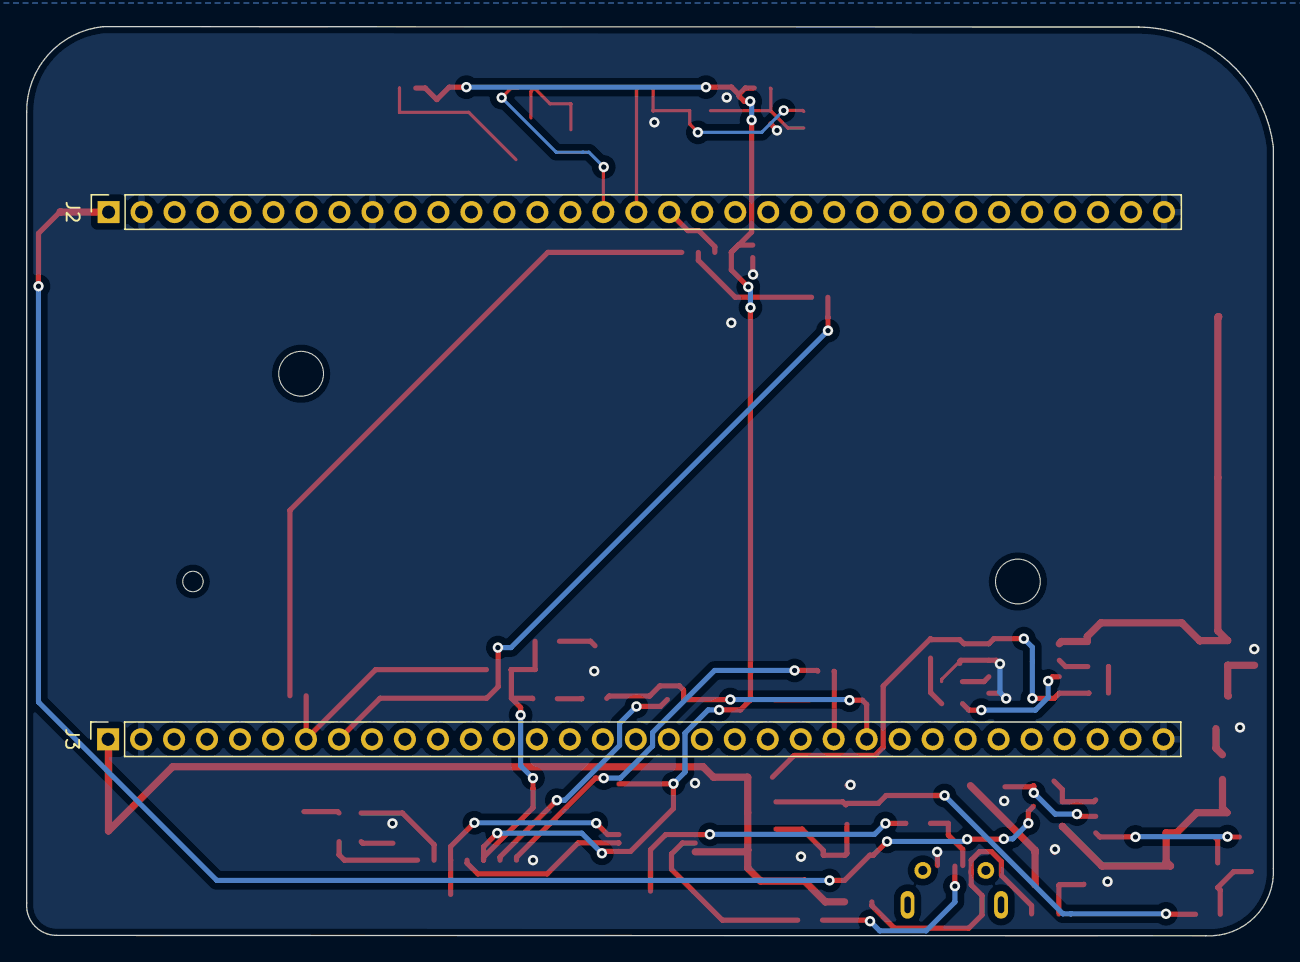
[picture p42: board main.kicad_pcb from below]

Board: 2 copper layers, 96.0 x 70.0 mm, 82 parts (2 on the bottom side), 52 nets.

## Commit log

2022-02-25 Create PCB_readme.md
    Still includes copied notes on options for KiCad Library setup
2022-02-25 Added power block to block diagram
2022-02-28 Upload KiCad Templates
    [main.kicad_pcb, main.kicad_sch, microcontroller_interfacing.kicad_sch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]
2022-03-02 Added sheet details to schematic
    [main.kicad_sch, microcontroller_interfacing.kicad_sch, outputs.kicad_sch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]
2022-03-02 Add Power Module Datasheets
    [power.kicad_sch]
2022-03-03 Add battery datasheet
2022-03-03 Power Module v0.01
    [main.kicad_sch, power.kicad_sch]
2022-03-04 Power Module v0.02
    [main.kicad_sch, microcontroller_interfacing.kicad_sch, outputs.kicad_sch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]
2022-03-04 Power module v0.02 update
    [main.kicad_sch, power.kicad_sch]
2022-03-04 Power Module v0.03
    [main.kicad_pcb, main.kicad_sch, power.kicad_sch]
2022-03-04 Power Module v0.04 Update
    [main.kicad_sch, power.kicad_sch]
2022-03-04 Add Power Module v0.04 Draft BOM
    [Power_v0-04_Draft.csv]
2022-03-04 Add Power Module v0.04 Draft BOM - Update Header
    [Power_v0-04_Draft.csv]
2022-03-04 Add Power Module v0.04 Draft BOM - Update Header & Columns
    [Power_v0-04_Draft.csv]
2022-03-04 uC SubModule v0.01
    [microcontroller_interfacing.kicad_sch]
2022-03-04 Add Microcontroller Interface v0.01 Draft BOM
    [Microcontroller_v0-01_Draft.csv]
2022-03-04 Add Mictrocontroller Interface v0.01 Draft BOM
    [Microcontroller_v0-01_Draft.csv]
2022-03-04 Sensing SubModule v0.01
    [main.kicad_sch, power.kicad_sch, sensing.kicad_sch]
2022-03-04 Add Sensing v0.01 Draft BOM
    [Sensing_v0-01_Draft.csv]
2022-03-11 Power v0.1, Sensing v0.1, uC Control v0.1, Simulations
    [main.kicad_sch, microcontroller_interfacing.kicad_sch, outputs.kicad_sch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]
2022-03-11 Power v0.1, Sensing v0.1, uC Control v0.1, ERC
    [main.kicad_sch, microcontroller_interfacing.kicad_sch, power.kicad_sch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]
2022-03-11 Add BOM v0.10
    [Group_7_BOM_v0_1_0.csv]
2022-03-17 Schematic updates
    [main.kicad_sch, microcontroller_interfacing.kicad_sch, power.kicad_sch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]
2022-03-17 Power, uC, Sensing v0.1.1
    [Group_7_BOM_v0_1_0.csv, main.kicad_sch, microcontroller_interfacing.kicad_sch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]
2022-03-19 Schematics v0.1.1 & PCB v0.01
    [Group_7_BOM_v0_1_0.csv, main.kicad_pcb, main.kicad_sch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]
2022-03-19 Upload Interactive BOM
2022-03-20 Add Power Module Schematic v0.1.1 Screenshot
2022-03-20 Add v0.1.1 BOM
    [Group_7_BOM_v0_1_1.csv]
2022-03-20 Add BOM v0.1.1
    [Group_7_BOM_v0_1_1.csv, main.kicad_sch, microcontroller_interfacing.kicad_sch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]
2022-03-20 Gerber, DRC text report, PCB v0.02
    [main-B_Cu.gbr, main-B_Mask.gbr, main-B_Paste.gbr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]
2022-03-25 Upload Week 6 Handin
    [main.kicad_pcb]
2022-04-11 v1.0 BOM, Gerbers & Final Designs
    [main-B_Cu.gbr, main-B_Mask.gbr, main-CuBottom.gbr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]
2022-04-11 v1.0 BOMs
    [Group_7_BOM_v1_0_0.csv]
2022-04-11 Interactive BOM v1.0
2022-04-11 Updated v1.0 - moved a decouplicng capacitor closer to pin
    [main-CuBottom.gbr, main-CuTop.gbr, main-EdgeCuts.gbr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]
2022-04-11 Updates to Microcontroller Circuit
    [Group_7_BOM_v1_0_0.csv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]
2022-04-18 Upload Power Schematic Screenshot v1.0
2022-05-18 Added Schematic PDF & Draft Report
2022-05-21 Update README.md
    Added new headings for setting up code & board
2022-05-21 Upload 3D Render of PCB image
